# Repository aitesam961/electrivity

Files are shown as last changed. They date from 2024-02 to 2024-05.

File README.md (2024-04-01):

# ELECTRIVITY: An EDGE IOT SYSTEM
A wireless IoT system with AI enhanced processing and automation.

### List of Hardware Components
- Check [HARDWARE](hardware/readme.md)
- Check [MQTT Topics](application/topics_mqtt.md)

## STATUS
In Progress.

- Hardware and Firmware : @aitesam961
- Mobile application and Linux Program: @Hassan & @Fawad

## File Naming Conventions

The project files follows a uniform file naming convention across the repository.

### Design Files: 
Design files should be placed under respective folders and DE project sources should be named as:
```
EVTY_FW_PIO_V1
EVTY: Electrivity
FW: Firmware 
PIO: Development Environment
V1: Version
```

The provided FNC follows guidelines provided by [MIT Data Management:
File Organization documents](https://ocw.mit.edu/courses/res-str-002-data-management-spring-2016/497580bd31c004cc758a2afb0a115aa4_MITRES_STR_002S16_File.pdf)
### Documents:
Documents must follow the naming order as the example below

```
EVTY_pres_sysd_v1.xls
EVTY: Electrivity
pres: presentation
sysd: Descriptor
v1: version
.xls: extension
```

### Directory Tree

```
.
├── archive
│   ├── _apppy
│   │   ├── blecclient.py
│   │   ├── blehandshake.py
│   │   └── bleserial.py
│   ├── BT_MAC_scan
│   │   └── BT_MAC_scan.ino
│   ├── _EIS_fw
│   │   ├── ESP_Control.cpp
│   │   ├── ESP_SENSOR.cpp
│   │   ├── firmware.code-workspace
│   │   ├── include
│   │   │   └── README
│   │   ├── lib
│   │   │   └── README
│   │   ├── platformio.ini
│   │   ├── src
│   │   │   └── main.cpp
│   │   └── test
│   │       └── README
│   └── ESP32_BTSerial
│       └── ESP32_BTSerial.ino
├── docs
│   ├── EVTY_arch_blueprint_v1.pdf
│   ├── EVTY_part_list_phase1_v1.pdf
│   ├── EVTY_part_list_prelim_v1.pdf
│   ├── EVTY_poc_demo_doc_v1.pdf
│   ├── EVTY_poc_demo_v1.drawio
│   ├── EVTY_poc_demo_v1.png
│   ├── EVTY_pres_phase1_v1.pdf
│   ├── im1.jpeg
│   ├── im2.jpeg
│   ├── im3.jpeg
│   ├── image_2024-02-22_001135263.png
│   ├── images
│   │   ├── image1.jpeg
│   │   ├── image2.jpeg
│   │   ├── image3.jpeg
│   │   ├── image4.jpeg
│   │   ├── image5.jpeg
│   │   └── image6.jpeg
│   ├── poc_demo.md
│   ├── prism-xp1_swd.drawio
│   ├── prism-xp1_swd.png
│   ├── prism-xp1_sysd.drawio
│   ├── prism-xp1_sysd.jpg
│   ├── readme.md
│   └── Report.pdf
├── firmware
│   ├── EVTY_FW_ARDPIO_v1
│   │   ├── debugger_esp.cpp
│   │   ├── esp32_r2.cpp
│   │   ├── esp32_r3.cpp
│   │   ├── esp32_r4.cpp
│   │   ├── esp32_s1.cpp
│   │   ├── esp_r1.cpp
│   │   ├── include
│   │   │   └── README
│   │   ├── lib
│   │   │   └── README
│   │   ├── platformio.ini
│   │   ├── src
│   │   │   └── main.cpp
│   │   └── test
│   │       └── README
│   ├── readme.md
│   └── test_builds
│       ├── r1_cRtos.c
│       └── s1_cRtos.c
├── hardware
│   ├── 3dmodel
│   │   ├── EVTY_stackupmodel_v1.blend
│   │   ├── EVTY_stackupmodel_v1.blend1
│   │   └── lib
│   │       ├── 4 Channel Relay Board.stl
│   │       ├── 4 Channel Relay Board.stp
│   │       ├── ESP32-DEVKITC-32D--3DModel-STEP-269445.STEP
│   │       ├── ESP32-DEVKITC-32D--3DModel-STEP-269445.stl
│   │       ├── m3-16mm.STEP
│   │       ├── m3-16mm.stl
│   │       ├── nut.STEP
│   │       ├── nut.stl
│   │       ├── Power_Board_asm.STEP
│   │       ├── Power_Board_asm.stl
│   │       ├── proto_7x5.stl
│   │       └── proto_7x5.stp
│   ├── EVTY_XP1_SBcase_v1p0
│   │   ├── CAM_Data
│   │   │   ├── EVTY_bracket_custom_v1p0-Prim Shell.step
│   │   │   ├── EVTY_bracket_custom_v1p0-Prim Shell.stl
│   │   │   ├── EVTY_bracket_custom_v1p0-Side Face.step
│   │   │   └── EVTY_bracket_custom_v1p0-Side Face.stl
│   │   └── src_freecad
│   │       ├── EVTY_bracket_custom_v1p0.FCStd
│   │       └── EVTY_bracket_custom_v1p0.FCStd1
│   ├── physical_addresses.md
│   ├── readme.md
│   └── schem
│       └── EVTY_Schematics_brd_v1.0.pdf
├── linux_app
│   ├── mqttapp.py
│   ├── mqtt_switch_control.sh
│   └── topics_mqtt.md
├── mobile_app
│   └── EVTY_distribution_plan_v1.md
├── osimage
│   └── readme.md
├── README.md
└── reference
    ├── mqtt-v5.0-os.pdf
    └── TTP223.pdf

30 directories, 82 files

```

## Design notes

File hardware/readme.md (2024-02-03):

## List of Components

| Component | Status  | Qty | Description |
|---|---|-----|---|
| -- Edge Device | | | |
| Raspberry Pi 5 | Acquired| 1 | 8GB |
| Pi5 Power Adapter (5V 5A) | YTA | 1 | |
| micro SD Card | Acquired| 1 | |
| Pi5 Active Cooler  | YTA | 1 | |
| micro HDMI adapter | YTA | 1 | |
| Coral TPU | YTA | 1 | USB-stick |
| | | | |
| -- Client Devices | | | |
| ESP32-Devkits | Acquired| 4 | wroom-32 (CP2102) |
| Relay module | Acquired| 1 | 4-channel |
| Current Sensor | YTA | 3 | zmct103-5a |
| Light sensor | Acquired| 3 | LDR with amplifier |
| Environment Sensor | Acquired| 2 | DHT-11 |
| Switch Board | Acquired| 1 | 4-Switch, 4-Sockets |
| Socket bulbs | Acquired| 2 | 220VAC |
| Power Adapter | Acquired| 3 | 5V-1A (micro-USB Cables)  |
| | | | 
| Misc. suppliers | | | |
| Perf-boards | Acquired| 2 | Dotted |
| Breadboard | Acquired| 2 | single-size |
| Wire 24AWG | Acquired| 1 | solid core pair (3m) |
| Wire 16AWG | Acquired| 1 | multi-stranded(2m) |
| Resistors | Acquired| 20  | 1k, 10k, 100k |
| Capacitors | Acquired| 10  | 1uF, 10uF |
| Terminal blocks | Acquired| 10  | 2p-3A |
| Thermal sleeve | Acquired| 2 | (20mm, 4mm) |

  ### Off-the-shelf Clients

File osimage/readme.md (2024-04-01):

### Raspberry Pi OS
- 64-bRaspberry Pi OS with desktop
- Release date: December 5th 2023
- System: 64-bit
- Kernel version: 6.1
- Debian version: 12 (bookworm)
- Size: 1,108MB
- [Release notes](https://downloads.raspberrypi.com/raspios_arm64/release_notes.txt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..)

$ sudo raspi-config params

- SSH Enabled
- Default boot to CLI (performance constraints)
- username: rpi
- password: rpirpi
- Wireless Interface
 (aitesam's home network) or can be configured

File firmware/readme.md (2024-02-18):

- ESP32-Devkit-A1 MAC_ADDR  [08:D1:F9:E7:DE:12]

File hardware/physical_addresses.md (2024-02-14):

## Physcial Addresses of ESP32 Servers

### E1
ESP32 MAC Address: 08:D1:F9:E7:DE:12

### E2 
ESP32 MAC Address: 08:D1:F9:E8:7E:7C

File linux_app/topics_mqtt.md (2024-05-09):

### List of MQTT topics
```
prism/board1/switch1
prism/board1/switch2
prism/board1/switch3
prism/board1/switch4

prism/board2/switch1
prism/board2/switch2
prism/board2/switch3
prism/board2/switch4

prism/board3/switch1
prism/board3/switch2
prism/board3/switch3
prism/board3/switch4

prism/board4/switch1
prism/board4/switch2
prism/board4/switch3
prism/board4/switch4

prism/board1/touch1
prism/board1/touch2
prism/board1/touch3
prism/board1/touch4

prism/board2/touch1
prism/board2/touch2
prism/board2/touch3
prism/board2/touch4

prism/board3/touch1
prism/board3/touch2
prism/board3/touch3
prism/board3/touch4

prism/board4/touch1
prism/board4/touch2
prism/board4/touch3
prism/board4/touch4

prism/sboard1/sensor1
prism/sboard1/sensor2
prism/sboard1/sensor3

prism/board1/pwrch1
prism/board1/pwrch2
prism/board1/pwrch3
prism/board1/pwrch4

prism/board2/pwrch1
prism/board2/pwrch2
prism/board2/pwrch3
prism/board2/pwrch4

prism/board3/pwrch1
prism/board3/pwrch2
prism/board3/pwrch3
prism/board3/pwrch4

prism/board4/pwrch1
prism/board4/pwrch2
prism/board4/pwrch3
prism/board4/pwrch4

```

**There are 4x switches/touches per board. As the first step, implement support for at least 4 boards.**

### Standard Message strings

#### From Client to RPi

- a = `high`

- a = `low`

#### From RPi to Clients

- publish(`on`)

- publish(`off`)

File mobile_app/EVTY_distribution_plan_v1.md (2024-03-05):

# XP-1: Client Distribution

Each room gets allocated a single board ID (i.e board1, board2 ...). This scheme will slightly differ for the production model.

### Bed Room:
```
prism/board1/switch1	
prism/board1/switch2
prism/board1/switch3
prism/board1/switch4
```
```
prism/board1/touch1
prism/board1/touch2
prism/board1/touch3
prism/board1/touch4
```
### Living Room:
```
prism/board2/switch1
prism/board2/switch2
prism/board2/switch3
prism/board2/switch4
```
```
prism/board2/touch1
prism/board2/touch2
prism/board2/touch3
prism/board2/touch4
```
### Kitchen:
```
prism/board3/switch1
prism/board3/switch2
prism/board3/switch3
prism/board3/switch4
```
```
prism/board3/touch1
prism/board3/touch2
prism/board3/touch3
prism/board3/touch4
```
### Lawn:
```
prism/board4/switch1
prism/board4/switch2
prism/board4/switch3
prism/board4/switch4
```
```
prism/board4/touch1
prism/board4/touch2
prism/board4/touch3
prism/board4/touch4
```

## Valid Strings

#### Switches

Hardware clients subscribe to `switch` topics across the network and read values. The valid string values are `on` and `off`. All other values execute exception case.

#### Touch

Hardware publishes the `touch` topics ON CHANGE ONLY. Whenever a user touches the sensor, a `high` signal is published and the publisher goes silent. The raspberry pi stores this `on` state until user touches the same sensor again OR mobile app changes the state. 
The valis strings for touch published by the user are `high` and `low`. The raspberry pi is responsible for exception handling in this regard.

### Add or Remove Devices

User can add or remove available devices through mobile app. RPi uses client.subscribe(x,x) or client.unsubscribe(x,x) functions of MQTT to add or remove devices. Mobile app uses its own set of signals to send or receive data from RPi that eventually execute addition or removal of devices.

**NOTE: No Sensors are active for this prototype. If mobile app may or may not include interface for sensors for XP-1 but production version will certainly use sensor inputs.**

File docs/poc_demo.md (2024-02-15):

# Proof-of-Concept Demonstration

## Setup
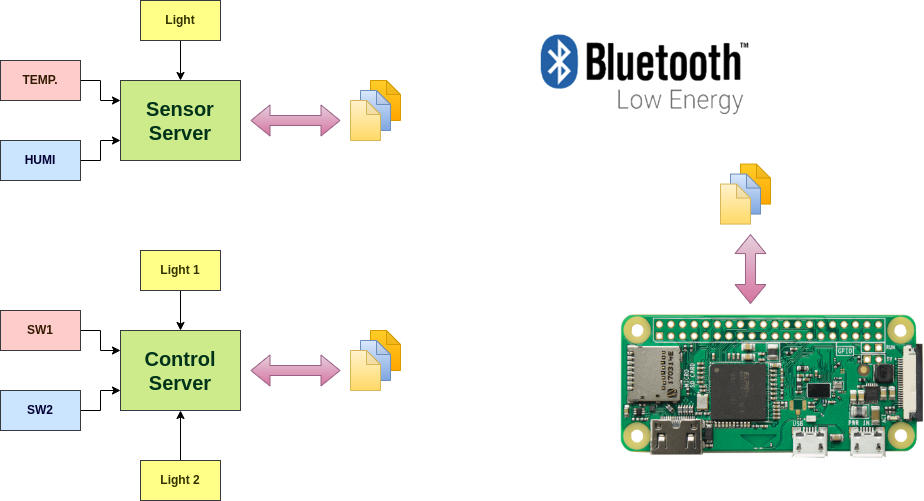
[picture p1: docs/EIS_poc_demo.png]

###  ESP32-S1  (Server 1)

Basically a sensor device. Integrates a DHT-11 temperature, humidity sensor and an analog light sensor. The ESP32 advertises a BLE GATT server profile and allows connection with Raspberry pi Client against known UUIDs.

Temp, Humi and Light intensity, each has a unique GATT chracteristic.The system is powered by a micro-USB power adapter.

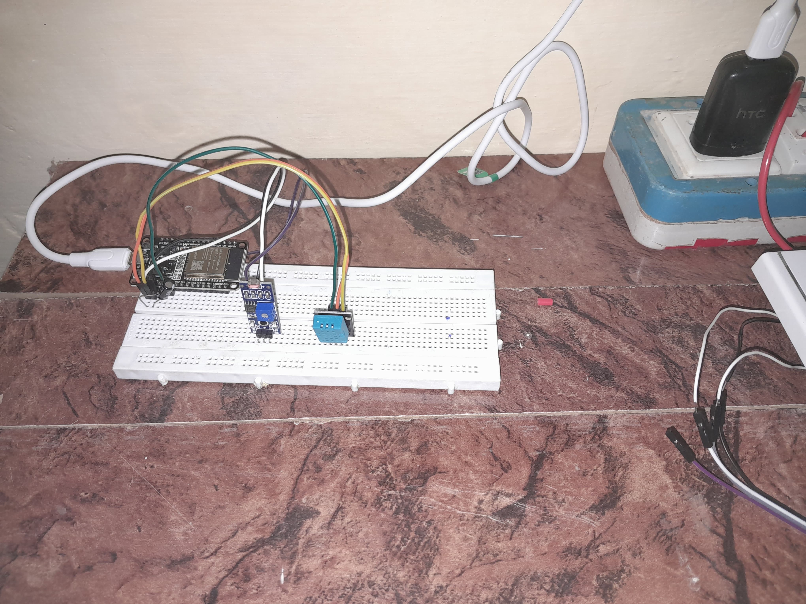
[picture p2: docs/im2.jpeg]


###  ESP32-S2  (Server 2)

Primarily acts as a relay controlling device. The GPIOs connect to a relay board. The resistors are for current limiting to keep ESP32 in safe operational range.The Relay board connects to a household Wall Switch board that has AC Bulbs for indication.

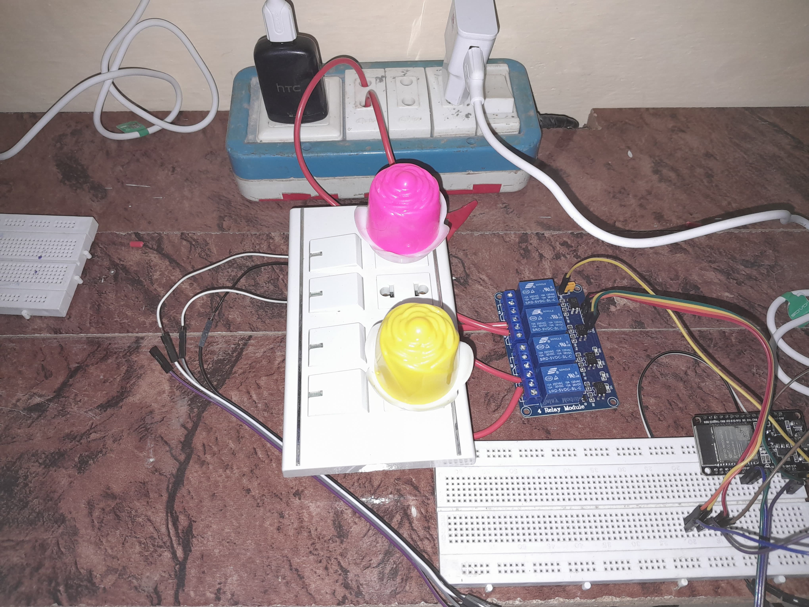
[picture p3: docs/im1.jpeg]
Im2


Moreover, the pushbuttons emulate user actions against switches. (Demo Alternative until current sensors arrive).

The system is powered by power adapter directly from the socket.

### Raspberry pi Zero W Central Client

Pi Zero W acts as a central client. (Pi-5 is not in use because of missing accessories.)

It runs a python program with root permissions. Makes use of bluepy library for bluetooth Communication profiles.
The UUIDs and MAC addresses of server devices are already stored in the program.

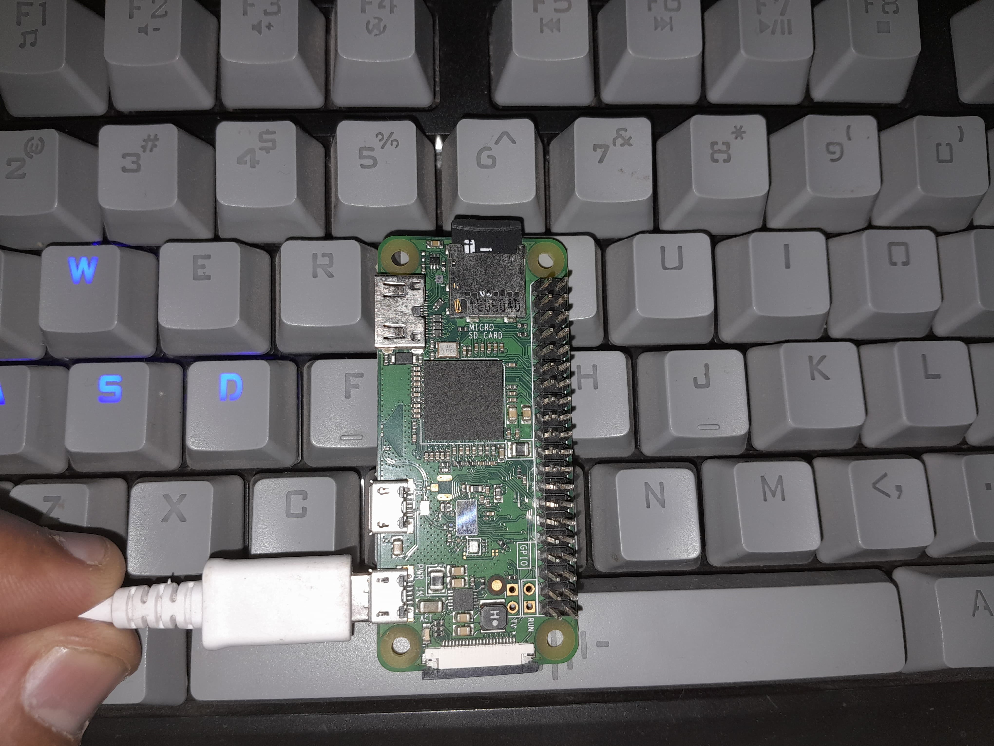
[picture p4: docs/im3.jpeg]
Im3


### Wireless Access Point

Not neccessary but helps access the pi thorugh SSH for convenient configuration. Eventually, would allow for WAN connection to mobile app.

## Operation
This demonstration includes a sensor server and a control server. The wireless communication is implemented using BLE GATT standard communication protocol.

At the boot-up, the servers wait for the central client to connect. At this time, a blue LED on ESP32 is turned ON. The Raspberry pi client connects to servers using their MAC addresses that are pre-defined in the client application.

After successful pairing, Sensor Service reads the sensor data and transmits a GATT Chracterisitic for each field. Raspberry Pi reads the chracteristics and asserts the control signals accordingly.

In this demo, one of the switch is dedicated to controlling yellow light. This presents the complete process of rpi client reading the switch through ESP32 and triggering the relay to turn ON. The Pink Light is triggered by an LDR. Whenever it finds the light is indufficient, it turns on the light. This demonstrated a sensor based decision.

### Operational Range

Using the BLE GATT channel with ESP32 connected to my Phone, I experienced a very good range of ~11 meters (apologies: 15 in the video was an approximate measurement). In case of ESP32 connected to raspberry pi zero w over BLE 4.2 GATT, I experienced the range dropping at ~4-5 meters.(BLE + WiFi active). So clearly, RPi is the bottleneck.

### Log (rpi console)

```
aitesam961@latitude:~$ ssh pi0wh@192.168.8.102
pi0wh@192.168.8.102's password: 
Linux raspberrypizero 6.1.0-rpi8-rpi-v6 #1 Raspbian 1:6.1.73-1+rpt1 (2024-01-25) armv6l

The programs included with the Debian GNU/Linux system are free software;
the exact distribution terms for each program are described in the
individual files in /usr/share/doc/*/copyright.

Debian GNU/Linux comes with ABSOLUTELY NO WARRANTY, to the extent
permitted by applicable law.
Last login: Thu Feb 15 13:28:32 2024 from 192.168.8.107
pi0wh@raspberrypizero:~ $ cd bleapp
pi0wh@raspberrypizero:~/bleapp $ ls
blecclient.py  blehandshake.py  bleserial.cpp  bleserial.py  readme.md
pi0wh@raspberrypizero:~/bleapp $ sudo python3 blecclient.py
Waiting for sensor notifications...
Temperature: 18 °C
Humidity: 43 %
Light Status: 0
Switch 1: 0
Switch 2: 1
Light 1 turned: ON
Light 2 turned: ON
Waiting for sensor notifications...
Temperature: 18 °C
Humidity: 43 %
Light Status: 1
Switch 1: 0
Switch 2: 1
Light 1 turned: OFF
Light 2 turned: ON
Waiting for sensor notifications...
Temperature: 18 °C
Humidity: 43 %
Light Status: 1
Switch 1: 0
Switch 2: 1
Light 1 turned: OFF
Light 2 turned: ON
Waiting for sensor notifications...
Temperature: 18 °C
Humidity: 43 %
Light Status: 1
Switch 1: 0
Switch 2: 1
Light 1 turned: OFF
Light 2 turned: ON
Waiting for sensor notifications...
Temperature: 19 °C
Humidity: 44 %
Light Status: 1
Switch 1: 0
Switch 2: 1
Light 1 turned: OFF
Light 2 turned: ON
Waiting for sensor notifications...
Temperature: 19 °C
Humidity: 44 %
Light Status: 0
Switch 1: 0
Switch 2: 1
Light 1 turned: ON
Light 2 turned: ON
Waiting for sensor notifications...
Temperature: 19 °C
Humidity: 44 %
Light Status: 1
Switch 1: 0
Switch 2: 1
Light 1 turned: OFF
Light 2 turned: ON
Waiting for sensor notifications...
Temperature: 19 °C
Humidity: 44 %
Light Status: 0
Switch 1: 0
Switch 2: 1
Light 1 turned: ON
Light 2 turned: ON
Waiting for sensor notifications...
Temperature: 19 °C
Humidity: 44 %
Light Status: 1
Switch 1: 0
Switch 2: 1
Light 1 turned: OFF
Light 2 turned: ON

```
### Summary

This is the proof-of-concept demonstration of the system working with basic features as reading from sensors and toggling light switches.
Several improvements and additions have yet to be made. However, this demonstration presents an end-to-end system operation with complete software stack implementation following the hard standards and best design practices.
More functionalities have yet to come.

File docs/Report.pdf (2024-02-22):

# Home Automation

Prepared by Hassan Malik
on Feb 21, 2024

Establish an MQTT broker on a Raspberry Pi for efficient device communication. Develop hardware devices (sensors, actuators) as MQTT clients.
Create a mobile app that connects to the MQTT broker, allowing users to monitor and control devices.
Implement real-time updates on the mobile app based on MQTT messages.

### PROJECT DESCRIPTION

### TOOLS

MQTT Broker: Mosquitto on Raspberry Pi.
Hardware: Custom devices acting as MQTT clients.
Mobile App: Developed using Flutter/React for cross-platform compatibility.

### FEATURES

Implemented MQTT connection logic in the Flutter/React Native app. Configured connection settings with the Raspberry Pi MQTT broker.
Developed an intuitive user interface for real-time monitoring and control using Flutter/React Native.
Enabled the app to subscribe to relevant MQTT topics for sensor data and control commands. Allowed users to control devices through the app, sending commands via MQTT.
Provided a consistent and user-friendly experience

### SECURITY MEASURES

Implemented username/password authentication for MQTT broker.
Ensured secure MQTT connections between the Flutter/React Native app and the broker. Encrypted sensitive data exchanged between devices and the app.

### FUTURE ENHANSMENT

Implementation of machine learning algorithms for predictive automation.
Expansion of device compatibility and support.

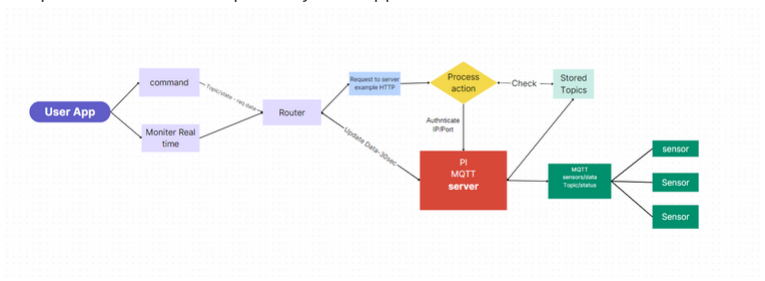
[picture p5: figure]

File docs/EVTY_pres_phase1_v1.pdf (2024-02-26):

# PRISM: An Edge IoT System for Home Automation

# Presentation: XP0.1

# Introduction

## A smart home automation and monitoring solution with focus on

security and privacy.

## This project makes use of Internet of Things to streamline the monitoring and control of household applications with special care to the user’s privacy and

security concerns.

# Quick Overview -I

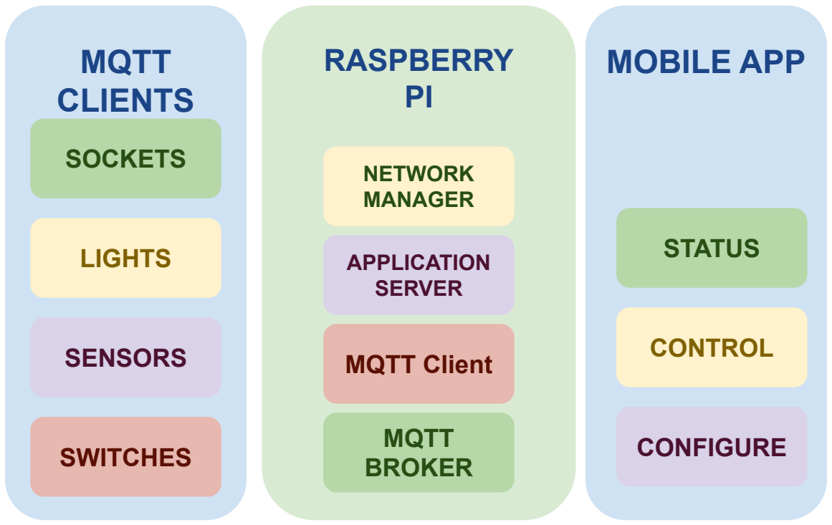
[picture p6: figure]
SOCKETS; LIGHTS; SENSORS; SWITCHES; MQTT CLIENTS; MQTT BROKER; APPLICATION SERVER; MQTT Client; NETWORK MANAGER; RASPBERRY PI; STATUS; CONTROL; CONFIGURE; MOBILE APP

# Network Architecture

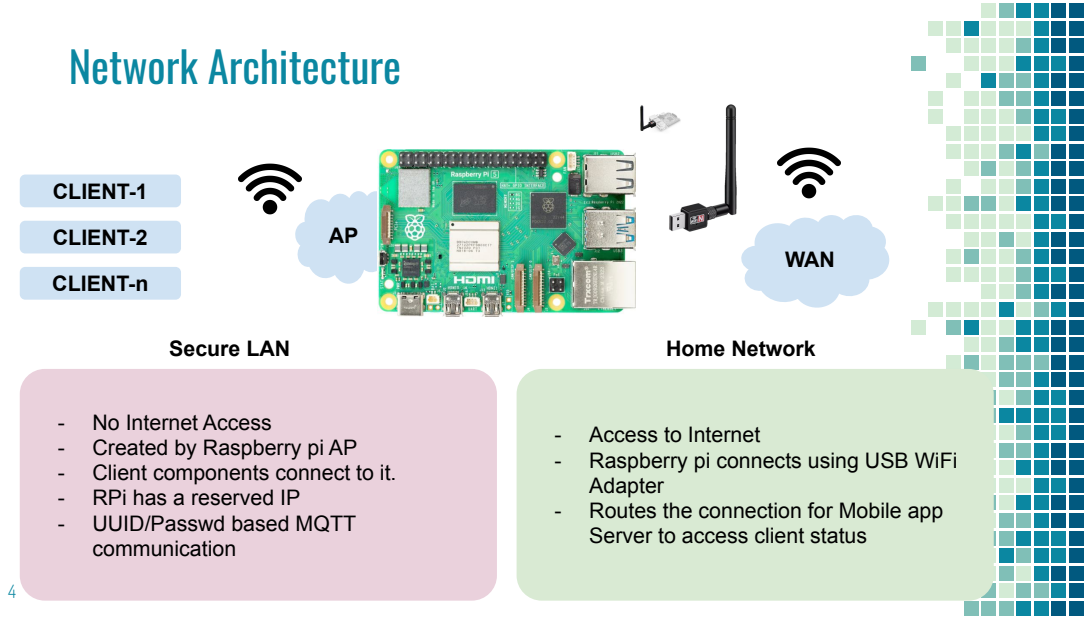
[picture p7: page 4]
Secure LAN; Home Network; CLIENT-1; CLIENT-2; CLIENT-n; WAN

- No Internet Access
- Created by Raspberry pi AP
- Client components connect to it.
- RPi has a reserved IP
- UUID/Passwd based MQTT
communication

- Access to Internet
- Raspberry pi connects using USB WiFi
Adapter
- Routes the connection for Mobile app
Server to access client status

# TYPICAL APPLICATION

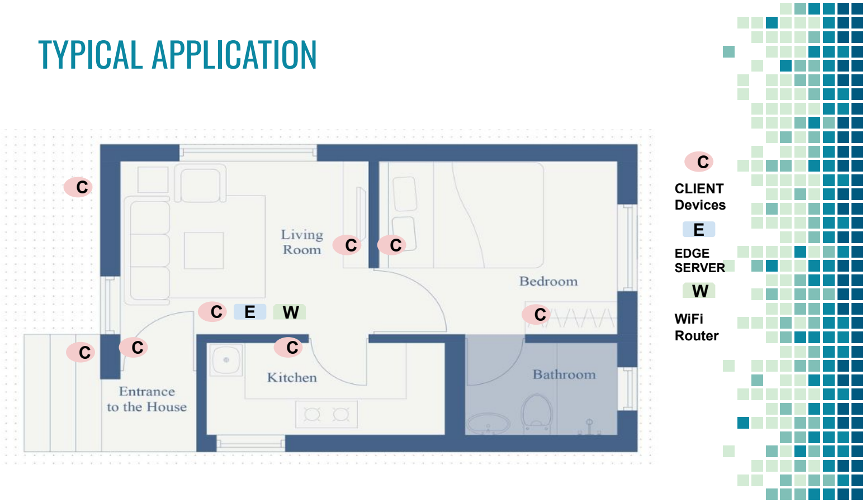
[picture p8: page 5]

C

C

C | C | C

C

C

C

E W

C

CLIENT
Devices

EDGE
SERVER

WiFi
Router

E

W

# XP0.1 Hardware Setup

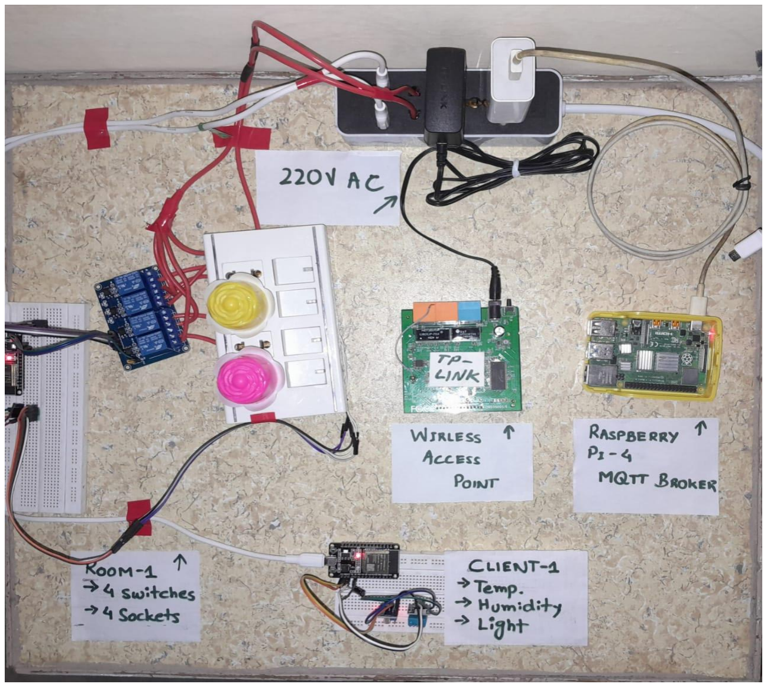
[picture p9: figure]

## - Raspberry pi Central Server - WiFi Access Point - Client-1: Sensors - Client-2: Household

switchboard (4-switch,

## 4-sockets) - Power Source (220VAC)

# Future Plans (XP1.0 and beyond)

XP1.0

# - A complete solution for monitoring and

controlling switchboards.
- End-to-end network and software stack.

# - Approach to a User Configurable, flexible

design.

# - Off-the-shelf Hardware components

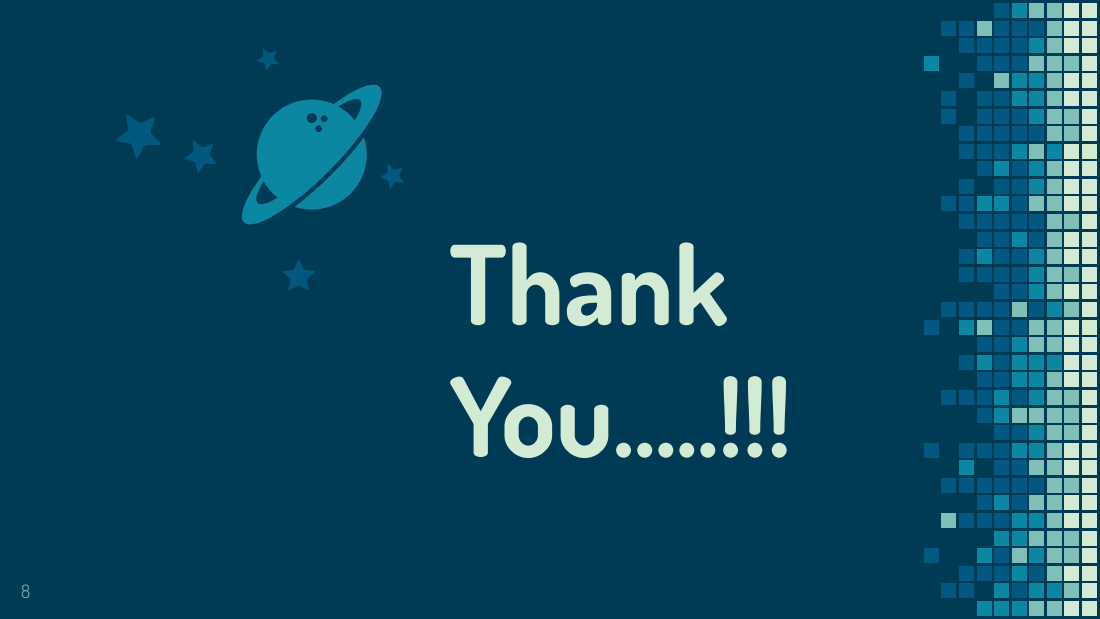
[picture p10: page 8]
Thank You…..!!!

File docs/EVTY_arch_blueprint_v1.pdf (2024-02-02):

# Edge IoT System

## ARCHITECTURAL BLUEPRINT

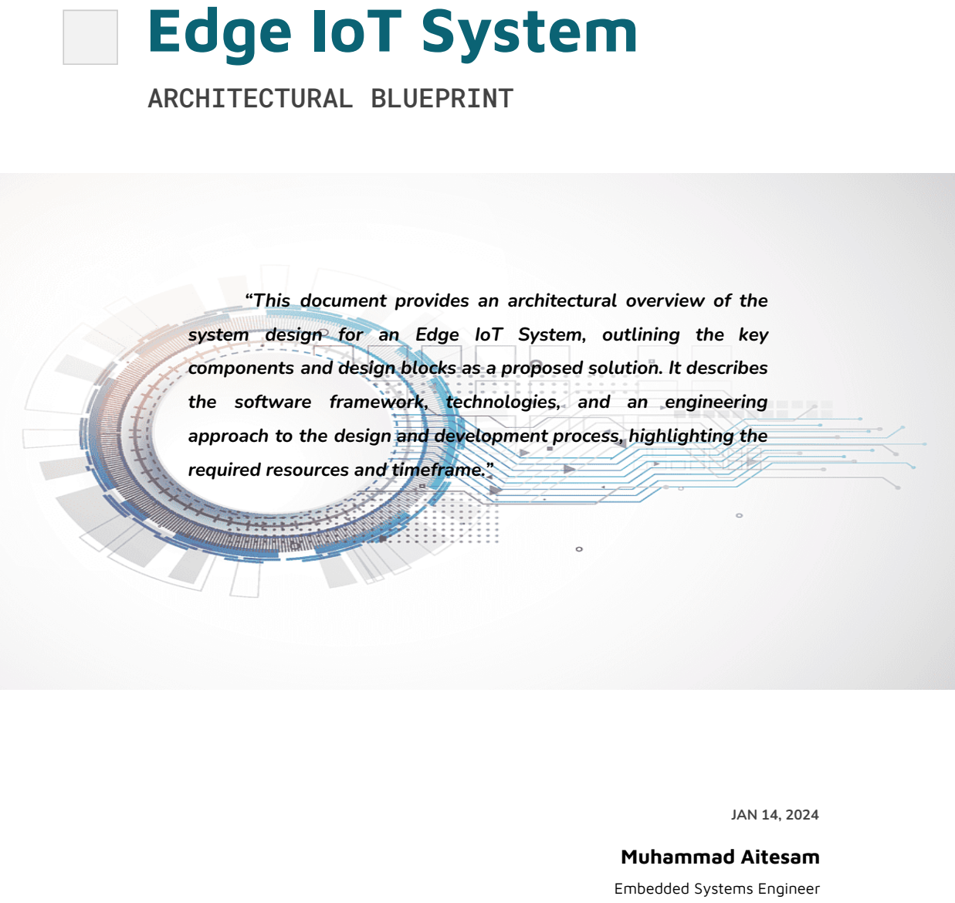
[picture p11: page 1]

“This document provides an architectural overview of the system design for an Edge IoT System, outlining the key components and design blocks as a proposed solution. It describes the software framework, technologies, and an engineering approach to the design and development process, highlighting the required resources and timeframe.”

JAN 14, 2024
Muhammad Aitesam

Embedded Systems Engineer

## 1. Project Overview

This document outlines development of an Edge IoT system focused on monitoring activities using a suite of sensors installed at the facility. Aimed at monitoring the activities of old age people, this system allows controlling household appliances remotely and monitoring status of multiple variables in real-time. Allowing users to access this data through mobile devices adds convenience to the monitoring and controlling practices. Artificial Intelligence aided processing further ensures the monitoring of usage patterns and allows an optimised control over the devices. Scalability and configurability are the key objectives that ensure a bespoke solution. To ensure user’s privacy, the system aims to store and process data within a local host without transmission to any remote database or client with the exception of a secure link to mobile application.
The system aims to support various types of input patterns including monitoring of appliances, doors and to keep track of medicine schedules for elderly.

## 2. Challenges

The scalable nature of this project poses a significant challenge to the design. It’s not only about adding new devices to the network. It includes modification at several layers in the design to accommodate those additions and changes. It covers the addition of software support for that device, adding its inputs to the compute layer to weigh in the data. Moreover, it requires adding blocks to the application layer in order to present that data to the user. Not all the sensors and control devices are the same as each may have data of a different category. The solution requires development of a generic software IO port that could offer compatibility with all types of supported input and output devices. The processing system needs to be able to recognize each device and weigh its data as per the demands.

## 3. Hardware

The initial prototype comprises off the shelf (COTS) hardware and modules for quicker PoC turnaround (C1 Hardware). After successful PoC, more improvements could be made to design customised hardware for sensor nodes and edge devices to ensure a more bespoke solution(C2 Hardware).

C1 Hardware

- Raspberry Pi 4, Raspberry Pi 5 is preferred
- Google Coral TPU (USB Accelerator for RPI4, M.2 PCIe Accelerator for RPI5)
- ESP32 Dev Kits / nRF52 Dev kits
- Sensor modules
- Controller modules (relays, FET switches etc)
- RPI GSM/ISM Cellular HATs
C2 Hardware
- RPI CM4 or RPI 5 SBC
- Custom designed carrier board
- USB Accelerator slot or M.2 Slot PCIe accelerator slot
- On Board Power Supply
- Custom Designed sensor nodes with integrated sensor + MCU
- Enclosure + Thermal relief system.

## 4. Software

- MQTT broker running on raspberry pi would allow integration of various modules and sensors with the core framework.
- MQTT Client running on MCU with RTOS enabled control.
- A configurator application (Flutter/React based) to allow taking commands from mobile app to add or remove devices and their respective data processing streams inside the main compute block.
- AI specific frameworks (Tensor/PyTorch etc)
- python3 based PyCoral compute offload to accelerator
- Zephyr RTOS for MCU

## 5. Systematic Block Design

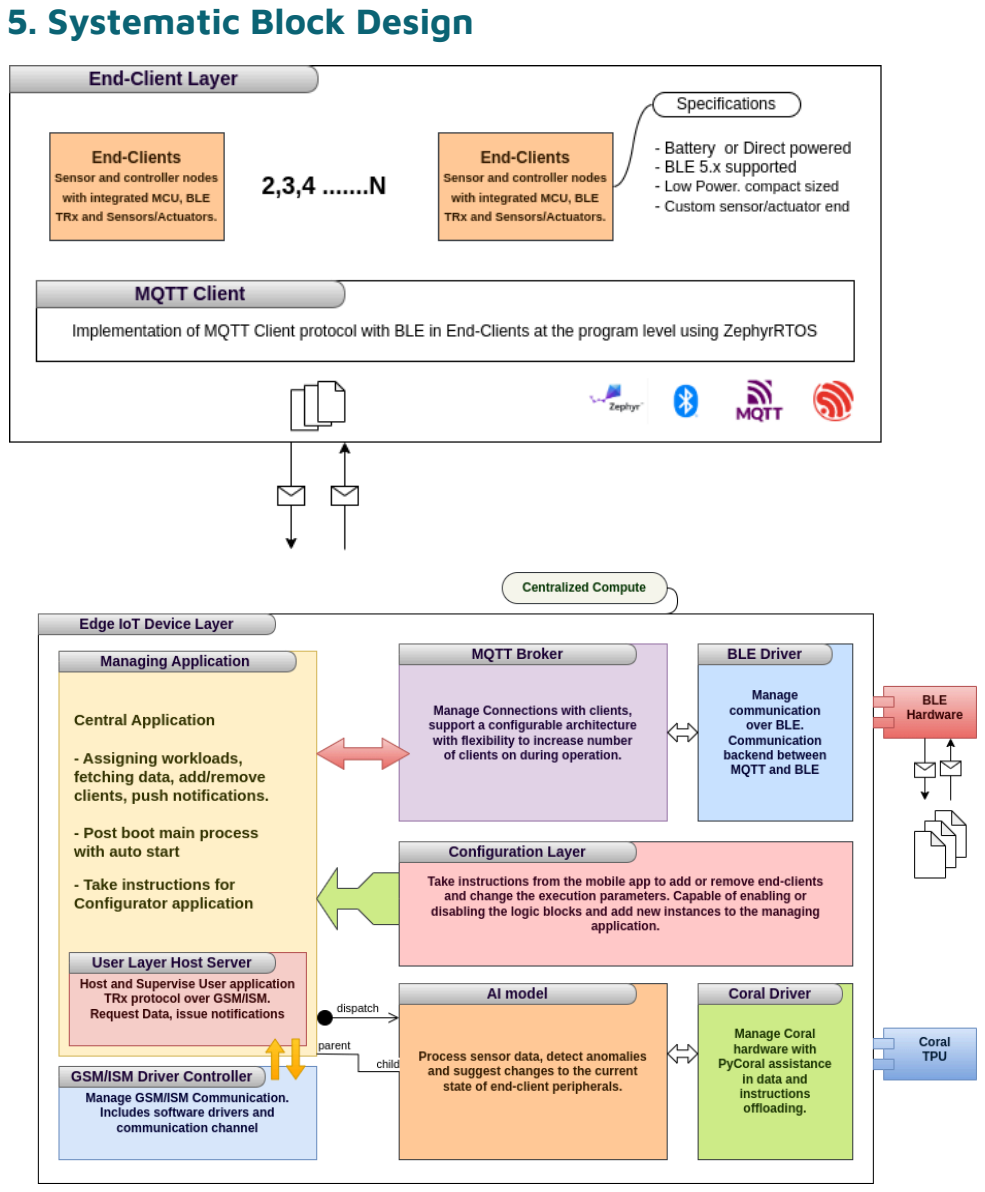
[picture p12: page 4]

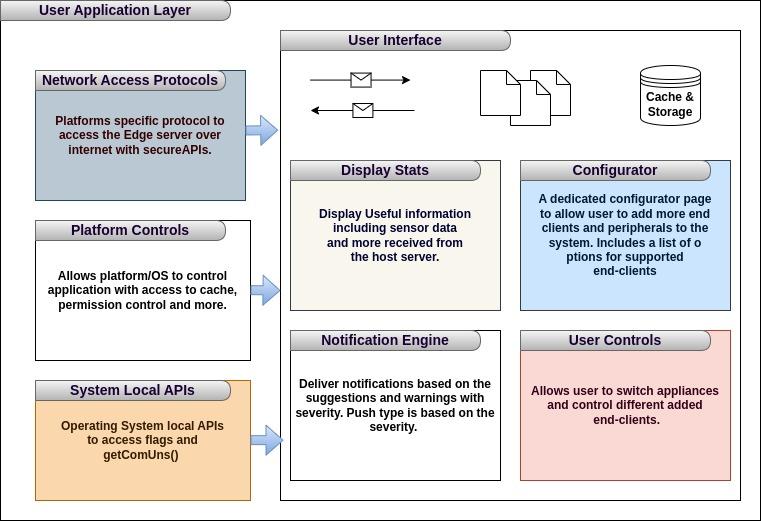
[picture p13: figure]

## 6. Resources

## Engineers and Developers:

1- AI Specialist

Requires experience with design and implementation of AI model to detect anomalies and provide suggestions based on the received sensor data. Understanding of optimization techniques for low power hardware are desired and experience with software integration is a plus.
2- Embedded Hardware Engineer

Requires experience with design of custom hardware with microcontrollers, wireless transceivers (BLE) and various types of sensors and actuators. Experience with manufacturing, board bring-up and troubleshooting is desired and understanding of firmware development is a plus.

Works closely with Embedded Software Engineer.
3- Embedded Software Engineer

Requires experience with creating custom applications in the linux environment. Experience with creating firmware for custom devices is desired and understanding of HAL (hardware abstraction layer) is a plus.

Works closely with Embedded Hardware Engineer and AI Specialist.

Note: May need more than x1 person for this role given the amount and scope of workload.
4- Mobile Application Developer

Requires experience with Android/IOS mobile apps including frontend and backend. Experience in creating a secure link with a custom host is required and understanding of secure communications is a plus.

Works closely with Embedded Software Engineer.

## Equipment and Workspace:

- Access to C1 Hardware
- Workspace and workstations for team

## 7. Expected Timeframe

With the availability of engineers and developers, a C1 Hardware based solution could be prepared for demonstration in ~3 months. For added compatibility and support for a wider range of devices, the customised hardware solution and with maximum capabilities and complete testing could be completed in expected 7-8 months. These estimates are based on my past experience. It may vary depending on expertise of the team and working conditions.

## About me

I am Aitesam, an engineering graduate with passion to work on embedded solutions.

I develop hardware and software solutions for commercial and industrial applications. Over the past 4 years, I undertaken several endeavours including my role as a freelance embedded solutions provider working with clients globally to develop electronics systems tailored to their requirements.

I also worked as a consultant helping my clients with expert review for their hardware designs before manufacturing, helping with troubleshooting and EMC compliance issues.

Over the last year, I have worked on development of FPGA based solutions including the development of RISC-V Vector extension for RV64 systems. It included design of architecture in compliance with RV-V Spec and the RTL implementation targeted for Xilinx Zynq-US+ FPGAs.

In regards to the IoT category, I have developed several systems for my clients. To name a few, I have developed multiple types of home automation equipment including DIN Rail mounted WiFi based controllers. To be more specific, I have developed a monitoring solution targeted for elderly care space. It included design of customised hardware to monitor the kitchen stoves to avoid the possibility of fire in case it is left open by mistake. Moreover, it involved monitoring the doors at home. The sensors were wirelessly connected to a raspberry pi powered hub running the MQTT broker. The hardware design featured highly efficient components enabling battery run-time of approx. 1.5 years.

I enjoy working on open source projects as a way to return back to the community. Which can be found on GitHub. For more information, check my LinkedIn profile.

Linkedin/MAitesam (http://www.linkedin.com/in/muhammad-aitesam) | Github/aitesam961 (https://github.com/aitesam961) | aitesam961@gmail.com

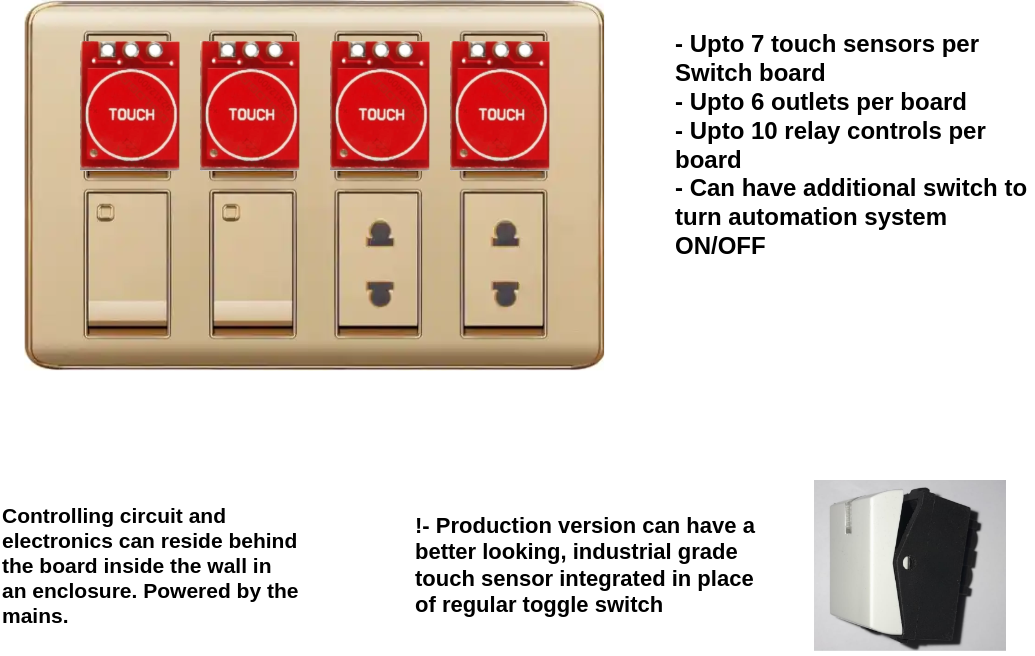
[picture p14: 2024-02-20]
docs/prism-xp1_swd.png

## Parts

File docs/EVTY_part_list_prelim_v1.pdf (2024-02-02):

# Edge IoT System

## N1: Hardware Components: Edge Device

Components | Qty | Ref URL | Comments
Raspberry Pi 5 | 1 | URL (https://www.raspberrypi.com/products/raspberry-pi-5/) | Already Acquired
RPI power Adapter | 1 | URL (https://www.raspberrypi.com/products/27w-power-supply/) | To be purchased
RPI Active cooler | 1 | URL (https://www.raspberrypi.com/products/active-cooler/) | To be purchased
micro SD Card | 1 | URL (https://www.daraz.pk/phone-micro-sd-cards/) | Already Acquired
Google Coral TPU | 1 | URL (https://coral.ai/products/accelerator) | To be purchased

## N2: Hardware Components: COTS integrated controllers

There are integrated sensor and wall socket solutions available in the market but for the vast majority of them, the key challenge is their proprietary wireless interface discouraging integration with custom devices. The very common example is Phillips Hue Bulbs. Many of such devices use WiFi and allow a very limited control in reprogrammability. We can never be sure about what communications these devices might want to establish over the internet.
However, some devices in this domain that feature a programmable microcontroller and BLE connectivity are hack-able which means with some tweaks, they can be re-programmed for a customized job as needed but there is no certainty of success with these devices. An example is Xiaomi MIjia Temperature sensor. (https://cloudfree.shop/product/xiaomi-mijia-bluetooth-temperature-and-humidity-sensor/) The same example applies to some switching and monitoring applications.
I have shortlisted a few of such devices in the table below. However, there is no guarantee of success with re-programmability and customizability for our needs. Please see comments for each option.

Device | Description | URL | Comments
Cloudfree Smart Plugs | Extension adapter for wall sockets. (SonOff S31) | URL (https://cloudfree.shop/product-category/smart-plugs/) | Integrated Controller. Runs Tasmota/ESPhome and is programmable with specialized builder and binaries.
Cloudfree Light Switch | Light Switch (1x SPDT) with ESP32 integrated controller | URL (https://cloudfree.shop/product/cloudfree-light-switch/) | Built around ESP32-C3 so very much configurable and controllable.
Athom Smart Plug | ESP32-C3 AU Plug V3 | URL (https://www.athom.tech/blank-1/tasmota-esp32-c3-au-plug-v3) | Built around ESP32-C3 so very much configurable and controllable.
Sonoff MINI R4 | An All purpose switch featuring ESP32 | URL (https://sonoff.tech/product/diy-smart-switches/minir4/) | Basically a multi-purpose controller for seamless integration inside wall sockets and switches
Shelly Plugs | A wide range of EU, US, AU, UK plugs with integrated ESP32 based controllers. | URL (https://www.shelly.com/en/products/shop/shelly-qubino-wave-i4-dc) | Basically a multi-purpose controller for seamless integration inside wall sockets and switches

The ESP32 is a very common chipset in the commercial home automations sector especially because of its high performance, low cost and easy availability. Moreover, it’s wireless frontend is FCC approved which makes it a suitable option in small batch commercial segment.
What’s important for us is that the ESP32 chipset has integrated WiFi/BLE and it is easily programmable over the standard UART interface which is easy to identify in custom boards. If we use an off-the-shelf integrated solution, we can likely access it’s programming interface with little effort. However it is not a guaranteed solution but has a good probability of success.

## N3: Hardware Components: Pre-assembled basic solutions

Device | Description | Comments
KiCony ESP32 Automation Controller (https://www.kincony.com/arduino-esp32-4-channel-relay-module.html) | Can be used without any Devkit. A pre assembled solution with 8-Channel Inputs and outputs | The main controller board integrat-able with different IO devices. Features integrated BLE/WiFi

## N4: Hardware Components: Self assembly solutions

Device | URL | Comments
ESP32-Dev Kits | URL (https://www.amazon.com/ESP32-WROOM-32-Development-ESP-32S-Bluetooth-Arduino/dp/B084KWNMM4) | The main controller board integrat-able with different IO devices. Features integrated BLE/WiFi
Relay Board (Already Acquired) | URL (https://digilog.pk/products/arduino-4-channel-relay-module-board) | Can be paired with ESP32-Devkit and placed inside wall-sockets to control outlets. Output Only.
Current Sensors (Zmct103c) | URL (https://digilog.pk/products/zmct103c-5a-range-single-phase-ac-active-output-onboard-precision-micro-current-transformer-module-current-sensor-for-arduino-in-p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) | Used to detect the condition of Switches (On/OFF). Moreover, it can measure the amount of current a particular appliance might be using. A cost effective solution for monitoring of power switches. To be used with ESP32-Devkit
Misc. Sensors | Please include more sensors of your choice | You can include other sensors of choice to increase the detectable variables e.g DHT11, MQ135 Gas sensor, Light sensors etc

Note: Each of the item (relays/sensors) in N4 Category require 1x ESP32 Devkit

## Summary:

N1 Category is our Edge device. All the components listed are required. In N2, I have mentioned some of the Off-the-shelf solutions that are integrat-able into our system. There is no certainty but higher probability of their compatibility. They require some reversing effort to access the terminal and program the integrated MCU. These devices are shortlisted after exploring several manufacturers and products from the internet.
N3 Category Hardware lists a pre-assembled solution capable of monitoring and controlling components along with an integrated ESP32 MCU and Wireless transceiver. There is a choice between N2, N3 and N4.
I believe the quickest way for now is to purchase N4 components as I believe they are available from the local market. They can be quickly assembled on a proto board and we can start using them. Downside is that this may not be the best looking solution. N2 hardware is a better solution but it will take some time in purchase + shipping and then disassembly of hardware in an attempt to program the chip. It may take several days to figure out the programming pattern for those N2 market products. One point to be noted is that N2 category products may not be a sustainable solution for commercialization as they are already the product of another company and there are complications involved. The best approach to commercial scaling of our solution would be to take our already tested (by then) N4 setup to a custom hardware design.

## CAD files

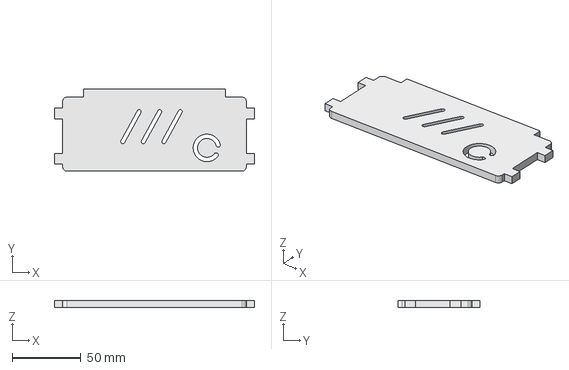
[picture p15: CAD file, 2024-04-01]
hardware/EVTY_XP1_SBcase_v1p0/CAM_Data/EVTY_bracket_custom_v1p0-Side Face.step
146.0 x 60.0 x 5.00 mm

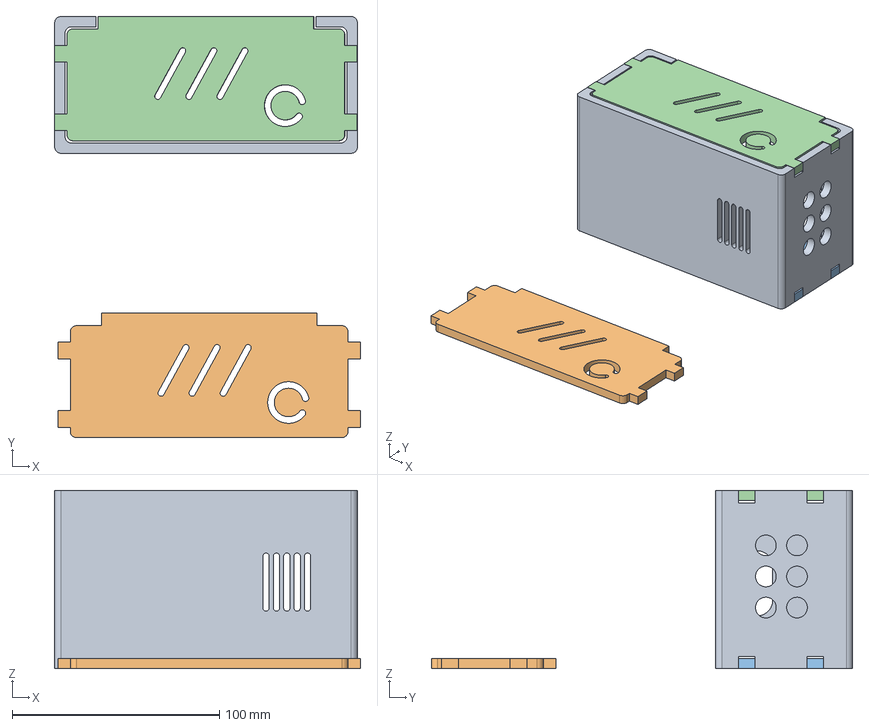
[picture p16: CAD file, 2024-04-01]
hardware/EVTY_XP1_SBcase_v1p0/src_freecad/EVTY_bracket_custom_v1p0.FCStd
147.6 x 203.2 x 86.1 mm
Prim Shell
Side Face

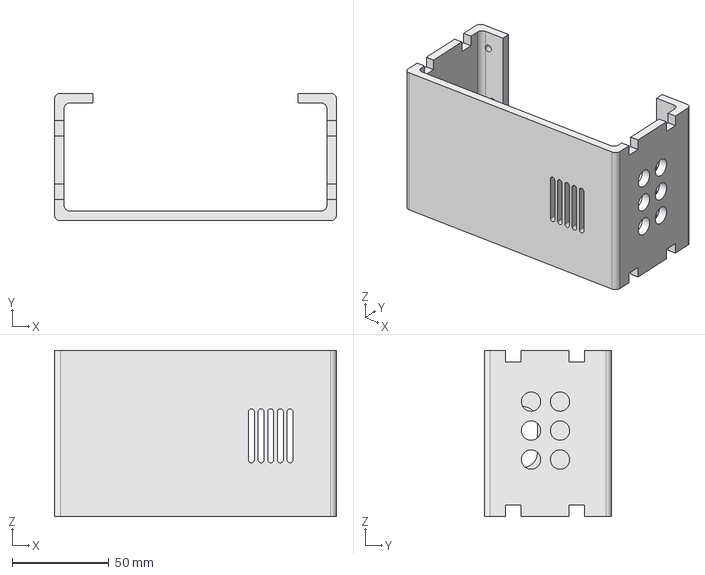
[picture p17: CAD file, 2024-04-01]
hardware/EVTY_XP1_SBcase_v1p0/CAM_Data/EVTY_bracket_custom_v1p0-Prim Shell.step
146.0 x 66.0 x 86.0 mm

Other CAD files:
hardware/EVTY_XP1_SBcase_v1p0/CAM_Data/EVTY_bracket_custom_v1p0-Prim Shell.dxf
hardware/EVTY_XP1_SBcase_v1p0/CAM_Data/EVTY_bracket_custom_v1p0-Prim Shell.stl
hardware/EVTY_XP1_SBcase_v1p0/CAM_Data/EVTY_bracket_custom_v1p0-Side Face.dxf
hardware/EVTY_XP1_SBcase_v1p0/CAM_Data/EVTY_bracket_custom_v1p0-Side Face.stl

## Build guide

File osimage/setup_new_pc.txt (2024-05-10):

===== Setting up MQTT Broker and relevant services on Linux PC/Raspberry pi replacement =====

# Install MQTT and MQTT client
sudo apt install -y mosquitto mosquitto-clients
# Install MQTT transmitter library
sudo pip3 install paho-mqtt

# To resolve Python Venv issue
sudo rm -rf /usr/lib/python3.11/EXTERNALLY-MANAGED
sudo pip3 install paho-mqtt

sudo nano /etc/mosquitto/mosquitto.conf
2) Move to the end of the file using the arrow keys and paste the following two lines:

listener 1883
allow_anonymous true

# Configure Network
nmcli dev
sudo nmcli device wifi hotspot ssid secureLAN password secureLAN ifname <replace with your WLAN interface name>

# Connect Wifi USB adapter to home network for internet
 nmcli device wifi connect LIAMAVENTA password 78900789 ifname wlx502b73c4193b

#Enable MQTT Broker
sudo systemctl enable mosquitto.service

###========================
Do each time

# Configure network if not in bashrc, else skip
Run MQTT host service

cd ~/Desktop/electrivity-main/linux_app
sudo python3 mqttapp.py

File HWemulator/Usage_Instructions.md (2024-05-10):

# Electrivity Hardware Emulator: Usage Guide

1- Connect target PC to secureLAN hotspot generated by RPI/host PC
2- Run `sudo python3 responder_hwemul.py`
3- Run `sudo txer_.sh` 
4- Enjoy :-)

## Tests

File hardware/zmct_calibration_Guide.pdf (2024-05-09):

## Tachyon Techs

Created by: M Aitesam

# Calibrate ZMCT103C

4

## th September 20XX

## OVERVIEW

Please follow the procedure below to calibrate ZMCT103C Sensors for Electrivity Project.

## PINOUT

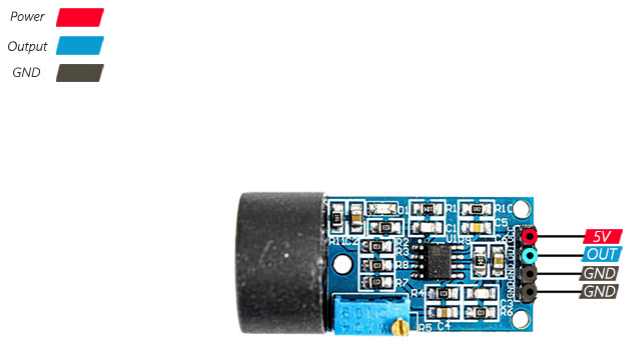
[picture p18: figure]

## Annotation

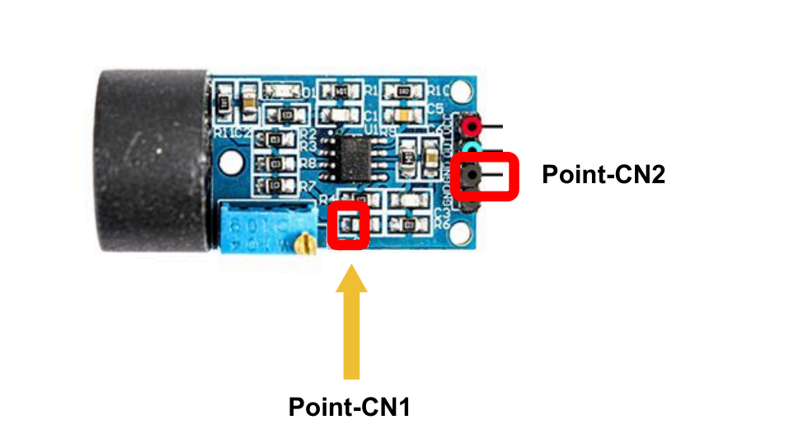
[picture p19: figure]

1. Place Multimeter probes on point-CN1 and CN2
2. Set Multimeter to Ohm measurement (>80k range)
3. Tune the Potentiometer until resistance is 20k Ohms
4. Connect to the device and check for any fluctuations in results.
5. If fluctuations are found, reset the potentiometer to max and then back to 20k.
6. Still found, try to remove any high voltage components from the surroundings of the sensor.

Please note:
Carefully wrap the GND wire around 5V and ADC wire to ensure maximum immunity to stray voltages. (see example in electrivity board #sensors 1 & 2)

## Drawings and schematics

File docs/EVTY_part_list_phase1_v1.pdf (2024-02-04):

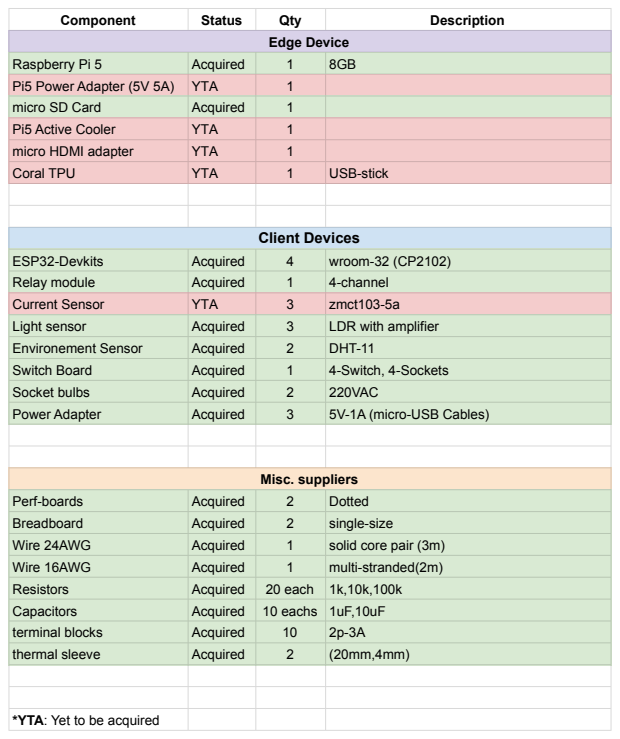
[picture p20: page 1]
Component; Status; Qty; Description; Edge Device; Raspberry Pi 5; Acquired; Pi5 Power Adapter (5V 5A); YTA; micro SD Card; Pi5 Active Cooler; micro HDMI adapter; Coral TPU; USB-stick; Client Devices; ESP32-Devkits; wroom-32 (CP2102); Relay module; 4-channel; Current Sensor; zmct103-5a; Light sensor; LDR with amplifier; Environement Sensor; DHT-11; Switch Board; 4-Switch, 4-Sockets; Socket bulbs; 220VAC; Power Adapter; 5V-1A (micro-USB Cables); Misc. suppliers; Perf-boards; Dotted; Breadboard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

*YTA: Yet to be acquired

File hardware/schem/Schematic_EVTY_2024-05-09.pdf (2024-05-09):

220VAC to 5V (1A<Imax<2A) | ESP32-Devkit-V1 | TTP223-Touch Sensor

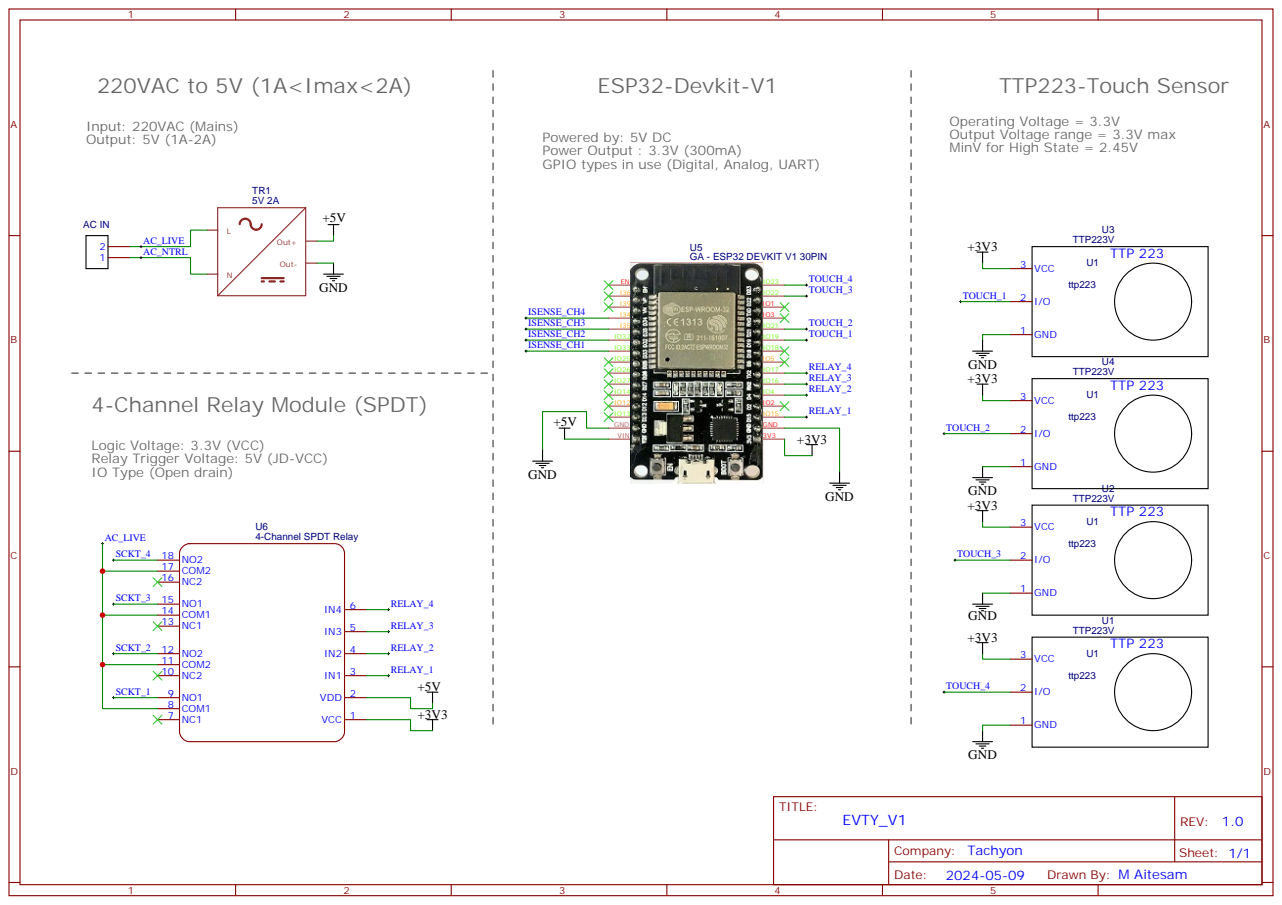
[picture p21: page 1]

Operating Voltage = 3.3V
Output Voltage range = 3.3V max
MinV for High State = 2.45V

Powered by: 5V DC
Power Output : 3.3V (300mA)
GPIO types in use (Digital, Analog, UART)

4-Channel Relay Module (SPDT)

Logic Voltage: 3.3V (VCC)
Relay Trigger Voltage: 5V (JD-VCC)
IO Type (Open drain)

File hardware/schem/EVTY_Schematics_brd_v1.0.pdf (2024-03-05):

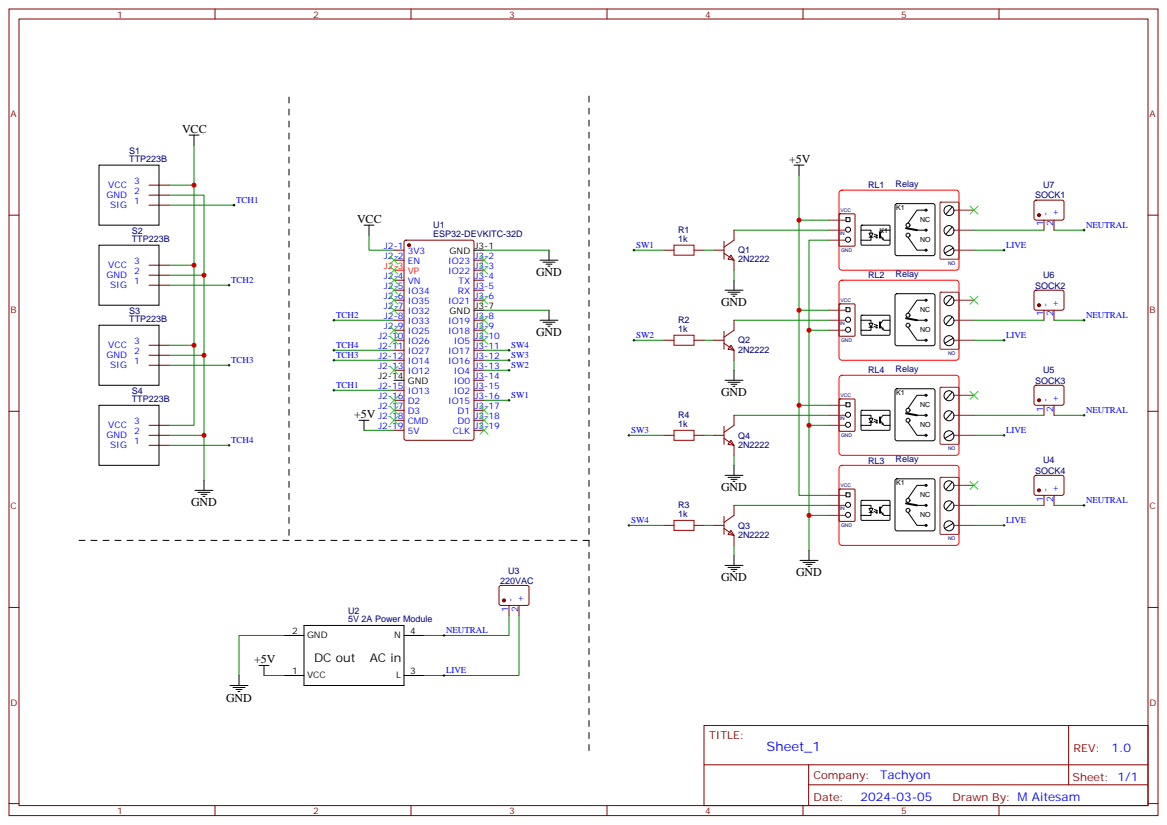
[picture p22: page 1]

GND 2
DC out AC in
VCC 1

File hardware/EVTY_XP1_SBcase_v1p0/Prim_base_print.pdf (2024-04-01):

Document Name: EVTY_bracket_custom_v1p0

Page / Page_projection
Page001 / Page_top
Page002 / Page_side
Page003 / Page_LR
Page004 / Page_bottom

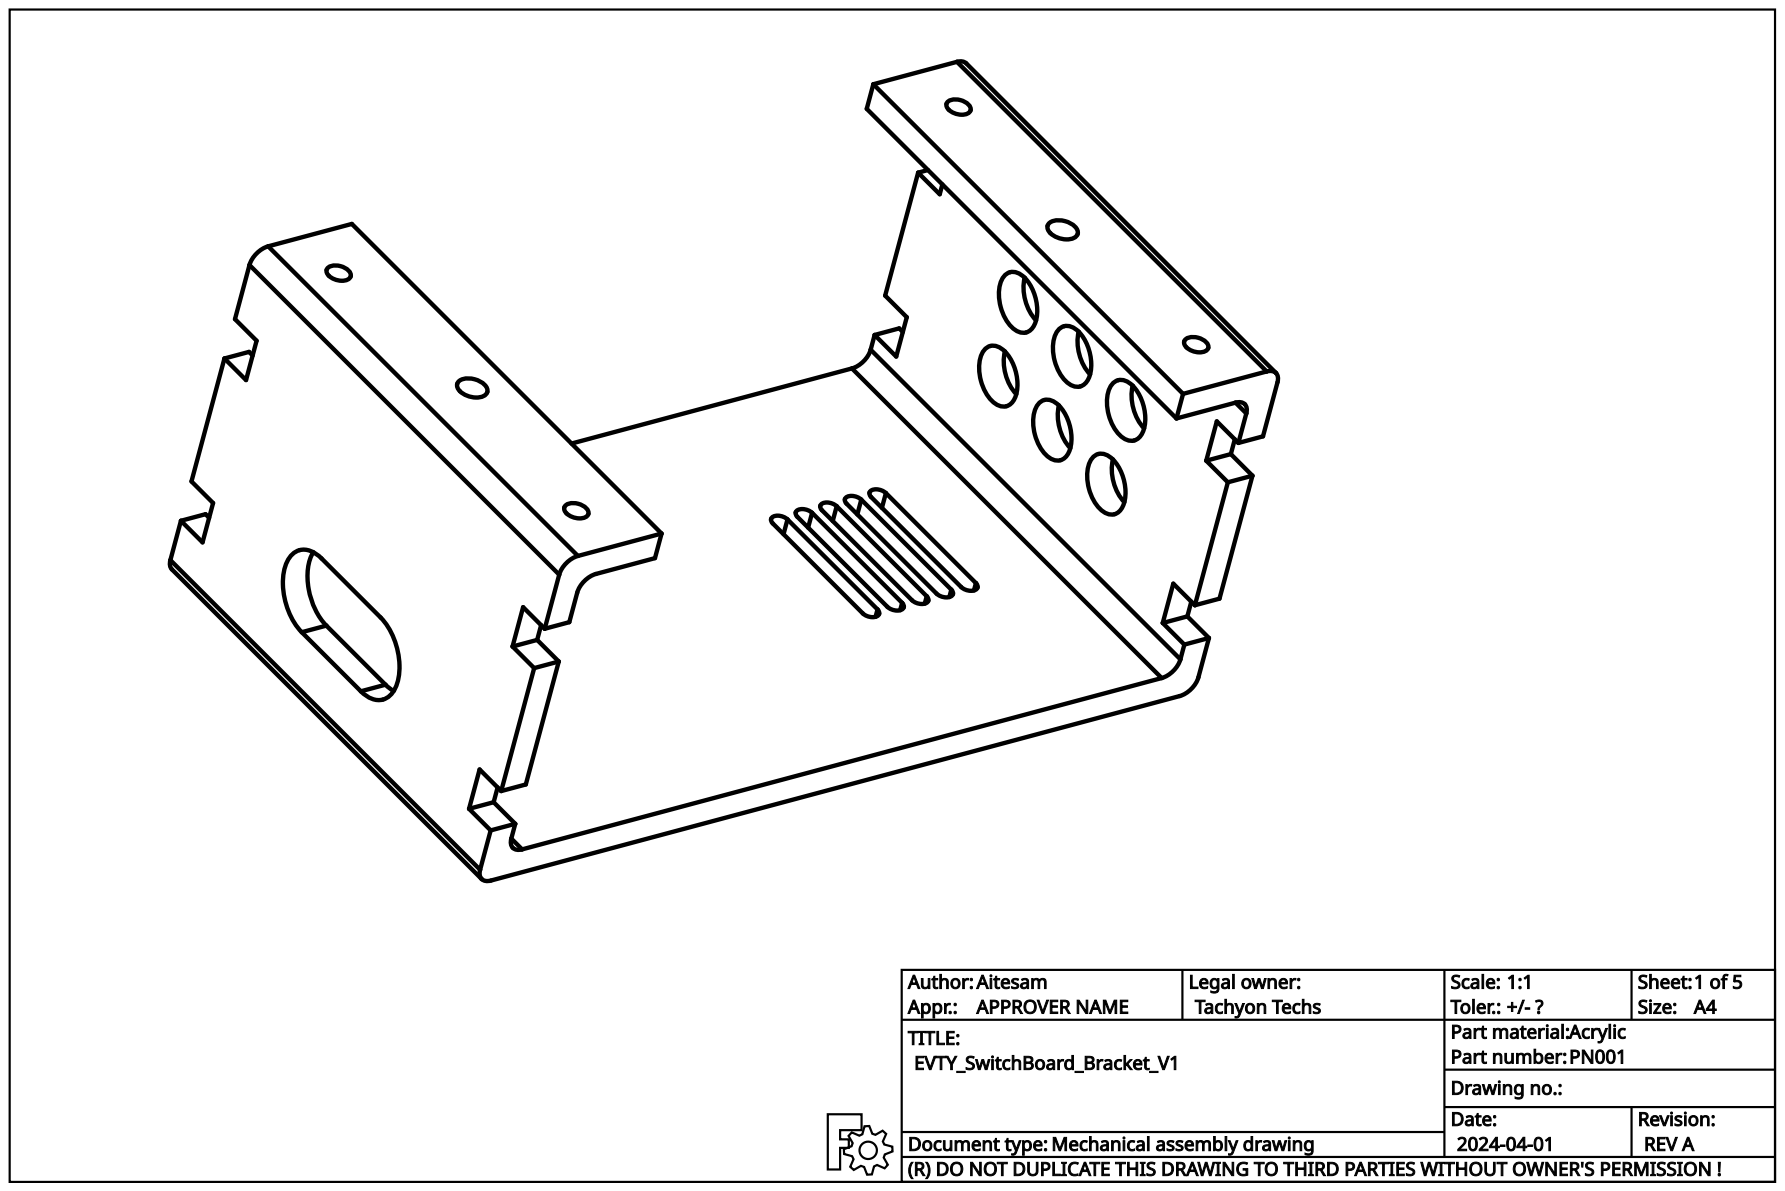
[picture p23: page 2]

3 12
2

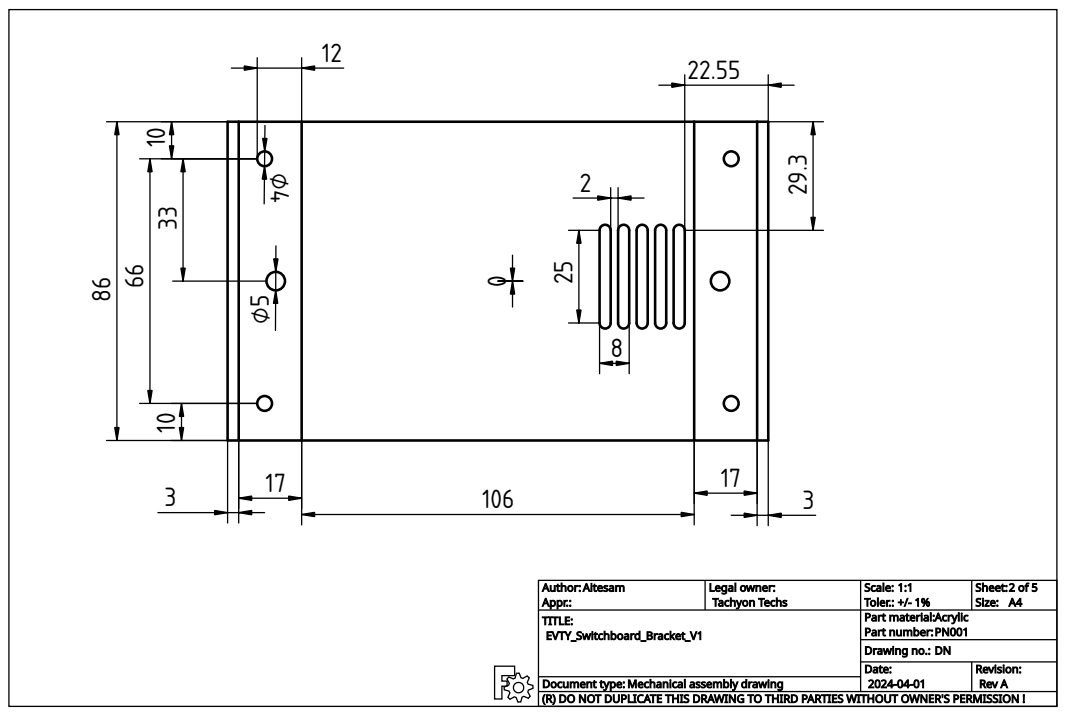
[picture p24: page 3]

2

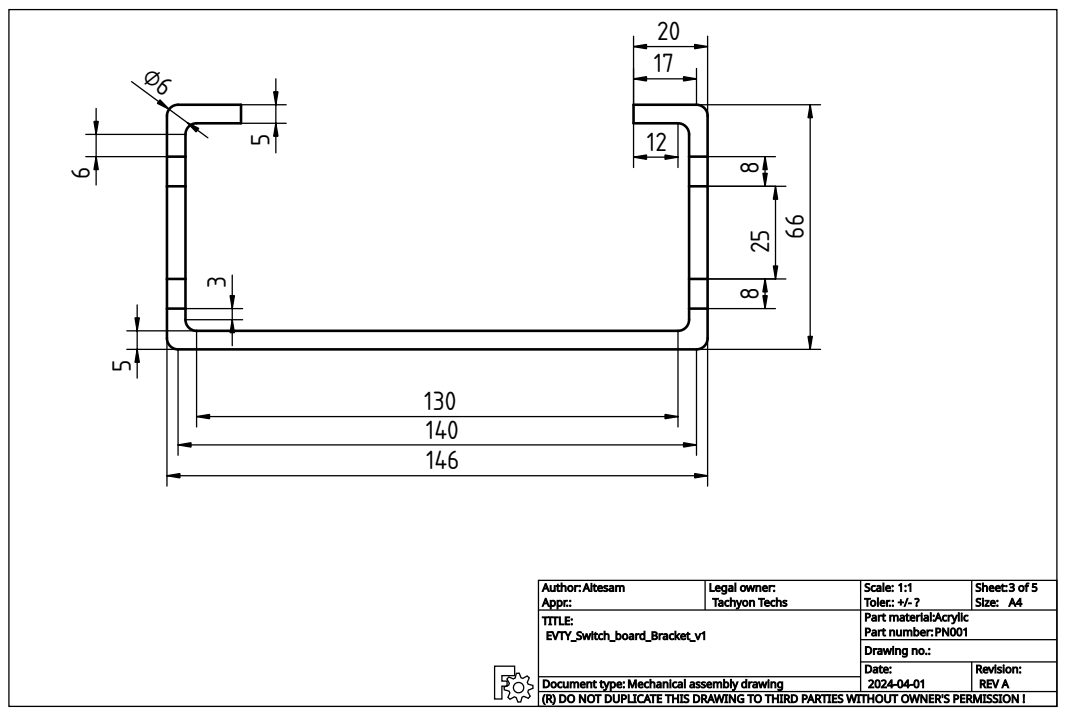
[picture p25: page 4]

8

6

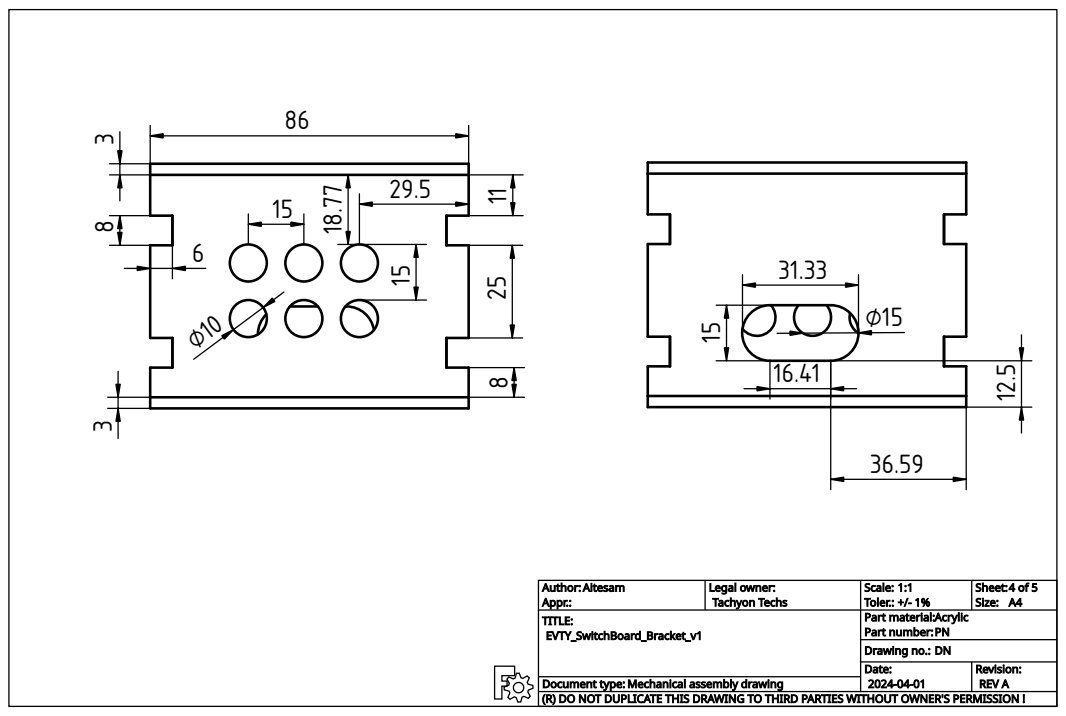
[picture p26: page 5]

3

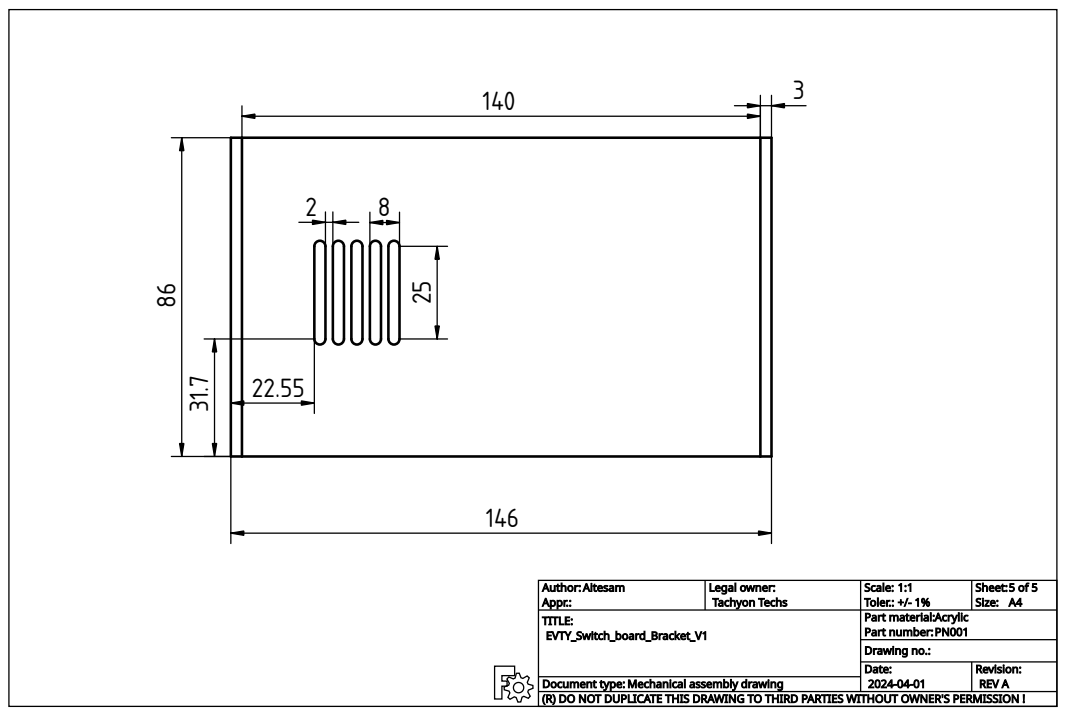
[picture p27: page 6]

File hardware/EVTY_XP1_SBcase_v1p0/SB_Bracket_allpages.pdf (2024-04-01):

Document Name: EVTY_bracket_custom_v1p0

Page / Page_projection
Page001 / Page_top
Page002 / Page_side
Page003 / Page_LR
Page004 / Page_bottom
Page005 / Projection_Side
Page006 / Top_Dim


3 12
2


2


8

6


3


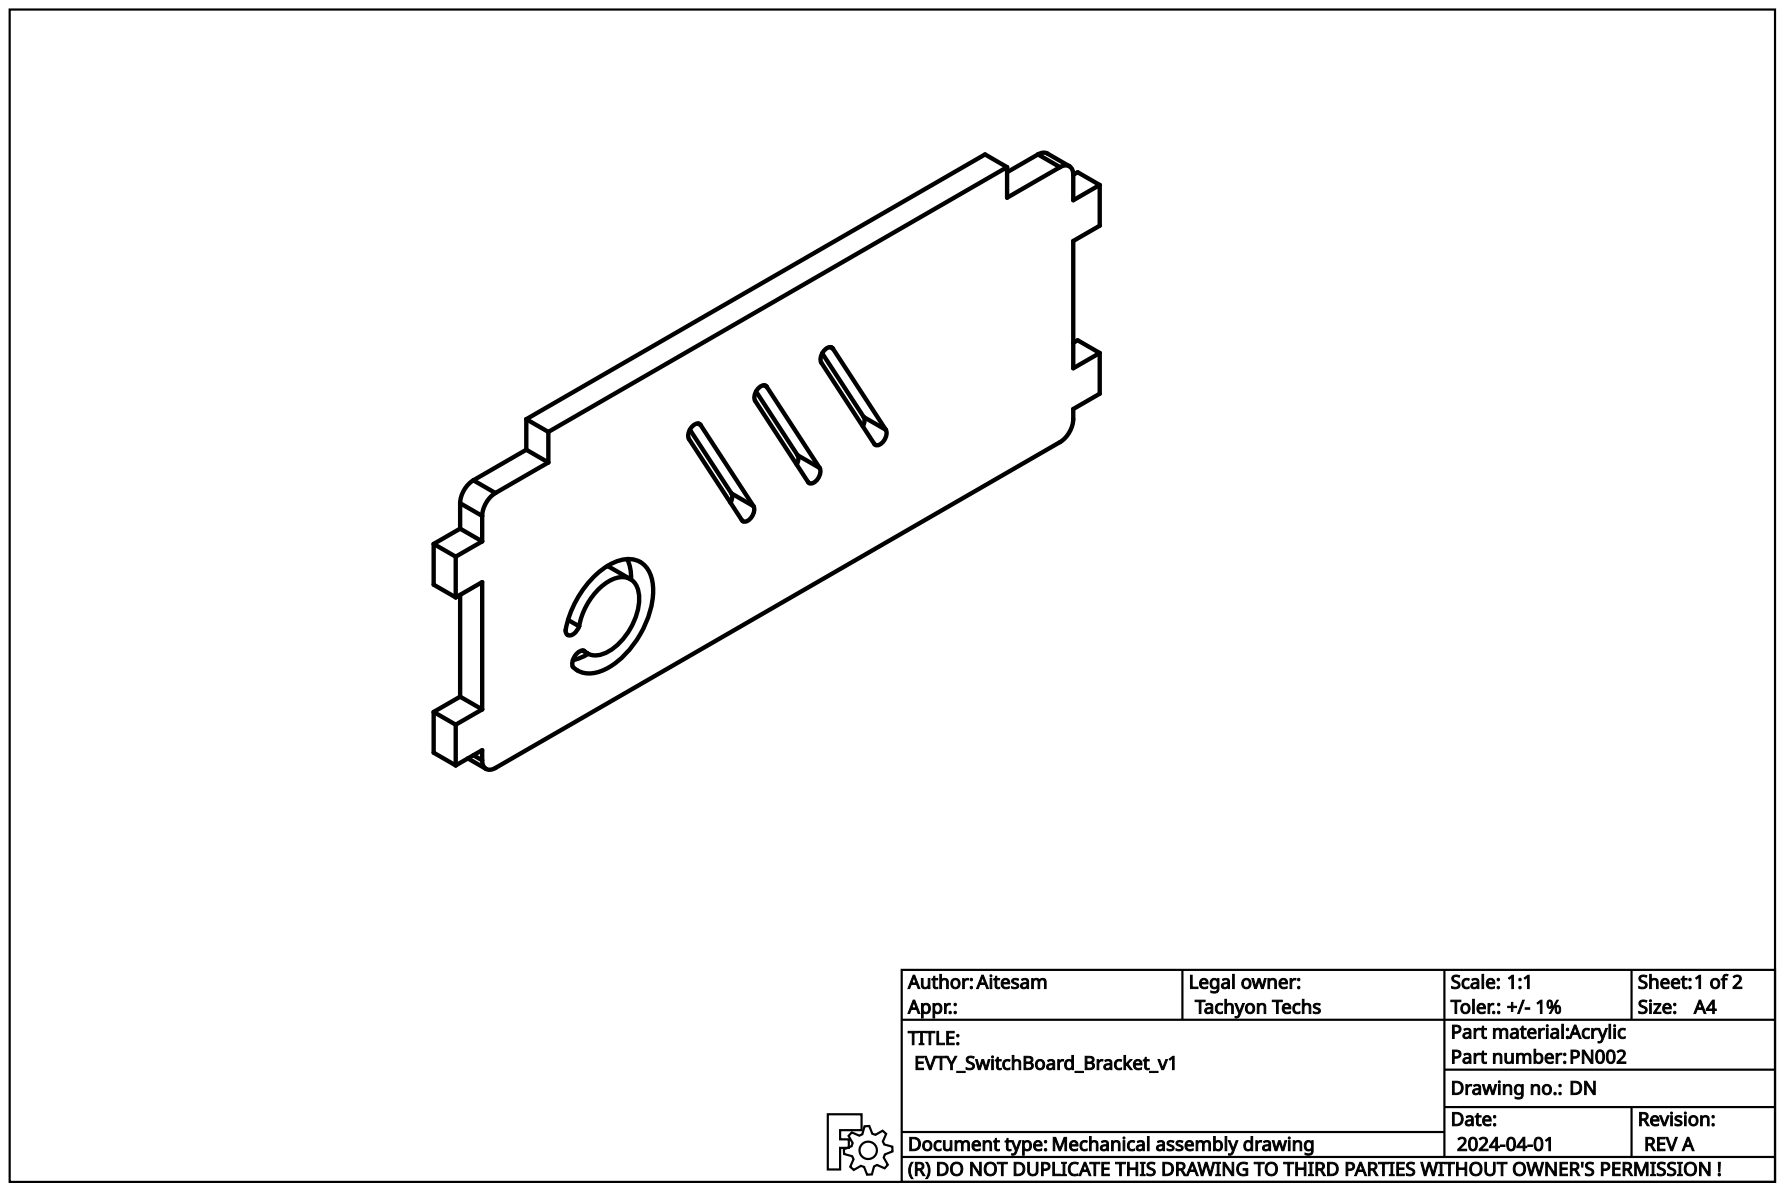
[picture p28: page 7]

10

412

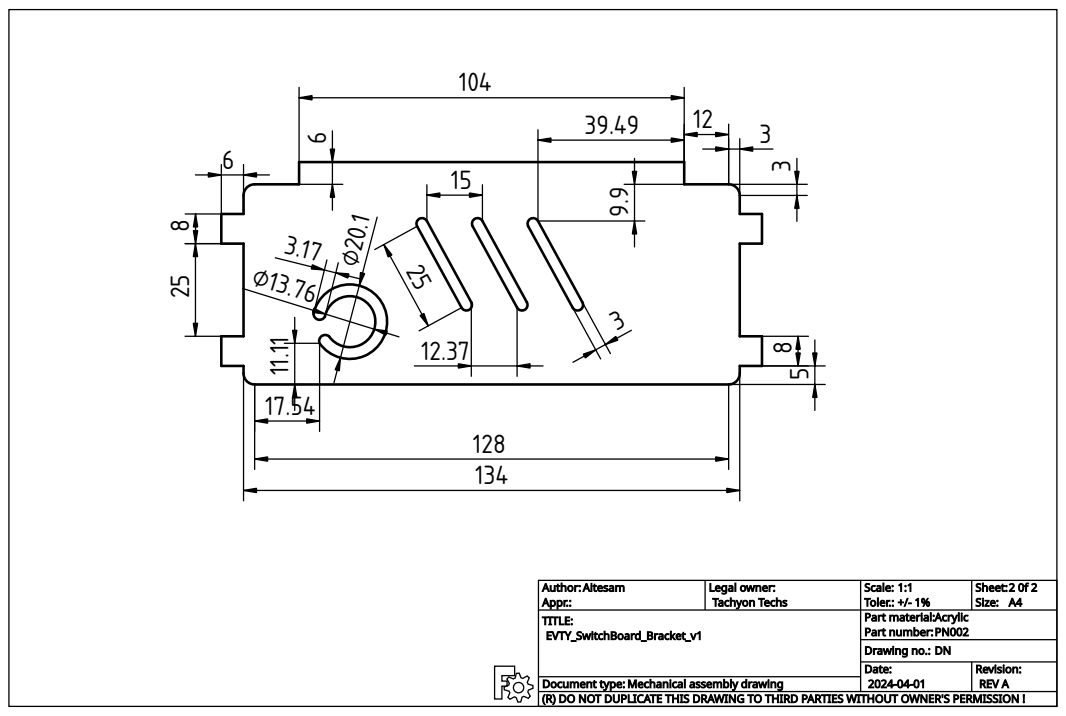
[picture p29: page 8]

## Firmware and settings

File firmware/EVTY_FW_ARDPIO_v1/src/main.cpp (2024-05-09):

/*
*
*  Project: PRISM
*  An Egde IoT System for home automation
*  
*  Author: aitesam961
*  
*  This is the main source file for ESP32 firmware written in arduino framework
*  
*
*/
#include<Arduino.h>
#include <WiFi.h>
#include "EmonLib.h"  
#include <PubSubClient.h>

#define  mains_voltage 220;

const char* ssid            = "secureLAN";
const char* password        = "secureLAN";
const char* mqttServer      = "10.42.0.1";
const int mqttPort          = 1883;
const char* mqttClientID    = "ESP32_ROOM_4";

const char* top_swh_1 = "prism/board4/switch1";
const char* top_swh_2 = "prism/board4/switch2";
const char* top_swh_3 = "prism/board4/switch3";
const char* top_swh_4 = "prism/board4/switch4";

const char* top_tch_1 = "prism/board4/touch1";
const char* top_tch_2 = "prism/board4/touch2";
const char* top_tch_3 = "prism/board4/touch3";
const char* top_tch_4 = "prism/board4/touch4";

const char* top_pch_1 = "prism/board4/pwrch1";
const char* top_pch_2 = "prism/board4/pwrch2";
const char* top_pch_3 = "prism/board4/pwrch3";
const char* top_pch_4 = "prism/board4/pwrch4";


const int switch1_pin     = 15;
const int switch2_pin     = 4;
const int switch3_pin     = 16;
const int switch4_pin     = 17;
 
const int touch1_pin      = 19;
const int touch2_pin      = 21;
const int touch3_pin      = 22;
const int touch4_pin      = 23;
 
const int led_pin         = 2 ;  

const int cts1_pin        = 33;
const int cts2_pin        = 32;
const int cts3_pin        = 35;
const int cts4_pin        = 34;

const int num_i_read      = 4;

uint8_t ttemp1 = 0;
uint8_t ttemp2 = 0;
uint8_t ttemp3 = 0;
uint8_t ttemp4 = 0;

double    Irms1 = 0;
double    Irms2 = 0;
double    Irms3 = 0;
double    Irms4 = 0;

u_int16_t powerch1, powerinitch1 = 0;
u_int16_t powerch2, powerinitch2 = 0;
u_int16_t powerch3, powerinitch3 = 0;
u_int16_t powerch4, powerinitch4 = 0;

char pch1[16];
char pch2[16];
char pch3[16];
char pch4[16];

uint16_t ct_iter_trace  = 0;

int avgfifo1[num_i_read] = {0};
int avgfifo2[num_i_read] = {0};
int avgfifo3[num_i_read] = {0};
int avgfifo4[num_i_read] = {0};


WiFiClient espClient;
PubSubClient client(espClient);

EnergyMonitor emon1;
EnergyMonitor emon2; 
EnergyMonitor emon3;  
EnergyMonitor emon4; 

void callback(char* topic, byte* payload, unsigned int length) {
  String message = "";
  for (int i = 0; i < length; i++) {
    message += (char)payload[i];
  }
  if (String(topic) == top_swh_1) {
    if (message == "on") {
      digitalWrite(switch1_pin, LOW);
      Serial.println("Relay-1 turned ON");
    } else if (message == "off") {
      digitalWrite(switch1_pin, HIGH);
      Serial.println("Relay-1 turned OFF");
    }
  }
  if (String(topic) == top_swh_2) {
    if (message == "on") {
      digitalWrite(switch2_pin, LOW);
      Serial.println("Relay-2 turned ON");
    } else if (message == "off") {
      digitalWrite(switch2_pin, HIGH);
      Serial.println("Relay-2 turned OFF");
    }
  }
  if (String(topic) == top_swh_3) {
    if (message == "on") {
      digitalWrite(switch3_pin, LOW);
      Serial.println("Relay-3 turned ON");
    } else if (message == "off") {
      digitalWrite(switch3_pin, HIGH);
      Serial.println("Relay-3 turned OFF");
    }
  }
  if (String(topic) == top_swh_4) {
    if (message == "on") {
      digitalWrite(switch4_pin, LOW);
      Serial.println("Relay-4 turned ON");
    } else if (message == "off") {
      digitalWrite(switch4_pin, HIGH);
      Serial.println("Relay-4 turned OFF");
    }
  }
}


void reconnect() {
  while (!client.connected()) {
    Serial.print("Connecting to MQTT Broker...");
    if (client.connect(mqttClientID)) {
        digitalWrite(led_pin, LOW);
        Serial.println("connected");
        client.subscribe(top_swh_1);
        client.subscribe(top_swh_2);
        client.subscribe(top_swh_3);
        client.subscribe(top_swh_4);
    } else {
        Serial.print("failed, rc=");
        Serial.print(client.state());
        Serial.println(" trying again in 5 seconds");
        digitalWrite(led_pin, HIGH);
        delay(2500);
        digitalWrite(led_pin, LOW);
        delay(2500);
    }
  }
}



void setup() {
  Serial.begin(115200);
  pinMode(led_pin, OUTPUT);
  digitalWrite(led_pin, HIGH);
  pinMode(touch1_pin, INPUT);
  pinMode(touch2_pin, INPUT);
  pinMode(touch3_pin, INPUT);
  pinMode(touch4_pin, INPUT);

  pinMode(switch1_pin, OUTPUT);
  pinMode(switch2_pin, OUTPUT);
  pinMode(switch3_pin, OUTPUT);
  pinMode(switch4_pin, OUTPUT);

  emon1.current(cts1_pin, 32.59);  
  emon2.current(cts2_pin, 32.59); 
  emon3.current(cts3_pin, 32.59); 
  emon4.current(cts4_pin, 32.59); 

  digitalWrite(switch1_pin, HIGH);
  digitalWrite(switch2_pin, HIGH);
  digitalWrite(switch3_pin, HIGH);
  digitalWrite(switch4_pin, HIGH);
  WiFi.begin(ssid, password);
  while (WiFi.status() != WL_CONNECTED) {
    delay(500);
    Serial.print(".");
  }
  Serial.println("");
  Serial.println("WiFi connected");
  client.setServer(mqttServer, mqttPort);
  client.setCallback(callback);
}



void loop() {
  if (!client.connected()) {
    digitalWrite(led_pin, HIGH);
    digitalWrite(switch1_pin, HIGH);
    digitalWrite(switch2_pin, HIGH);
    digitalWrite(switch3_pin, HIGH);
    digitalWrite(switch4_pin, HIGH);
    reconnect();
  }
  client.loop();
  
  uint8_t switchState1 = digitalRead(touch1_pin);
  if (switchState1 == 1) {
    if(ttemp1 == 0){
      client.publish(top_tch_1, "high");
      Serial.println("Touch-1 HIGH");
      ttemp1 = 1;
    }
  }
  else{
    ttemp1 = 0;
    Serial.println("Resetting_TTEMP");
  }

  uint8_t switchState2 = digitalRead(touch2_pin);
  if (switchState2 == 1) {
    if(ttemp2 == 0){
      client.publish(top_tch_2, "high");
      Serial.println("Touch-2 HIGH");
      ttemp2 = 1;
    }
  }
  else{
    ttemp2 = 0;
    Serial.println("Resetting_TTEMP");
  }

  uint8_t switchState3 = digitalRead(touch3_pin);
  if (switchState3 == 1) {
    if(ttemp3 == 0){
      client.publish(top_tch_3, "high");
      Serial.println("Touch-3 HIGH");
      ttemp3 = 1;
    }
  }
  else{
    ttemp3 = 0;
    Serial.println("Resetting_TTEMP");
  }

  uint8_t switchState4 = digitalRead(touch4_pin);
  if (switchState4 == 1) {
    if(ttemp4 == 0){
      client.publish(top_tch_4, "high");
      Serial.println("Touch-4 HIGH");
      ttemp4 = 1;
    }
  }
  else{
    ttemp4 = 0;
    Serial.println("Resetting_TTEMP");
  }

  Irms1 = emon1.calcIrms(1480);
  Irms2 = emon2.calcIrms(1480);
  Irms3 = emon3.calcIrms(1480);
  Irms4 = emon4.calcIrms(1480);

  powerch1  = (Irms1/100)*mains_voltage;
  powerch2  = (Irms2/100)*mains_voltage;
  powerch3  = (Irms3/100)*mains_voltage;
  powerch4  = (Irms4/100)*mains_voltage;

if(ct_iter_trace < num_i_read){
  avgfifo1[ct_iter_trace] = powerch1;
  avgfifo2[ct_iter_trace] = powerch2;
  avgfifo3[ct_iter_trace] = powerch3;
  avgfifo4[ct_iter_trace] = powerch4;

  ct_iter_trace +=  1;
}
else{
  ct_iter_trace = 0;

  powerinitch1  = ((avgfifo1[0]+avgfifo1[1]+avgfifo1[2]+avgfifo1[3])/4);
  powerinitch2  = ((avgfifo2[0]+avgfifo2[1]+avgfifo2[2]+avgfifo2[3])/4);
  powerinitch3  = ((avgfifo3[0]+avgfifo3[1]+avgfifo3[2]+avgfifo3[3])/4);
  powerinitch4  = ((avgfifo4[0]+avgfifo4[1]+avgfifo4[2]+avgfifo4[3])/4);

  powerinitch1  = powerinitch1 < 5 ? 0 : powerinitch1;
  powerinitch2  = powerinitch2 < 5 ? 0 : powerinitch2;
  powerinitch3  = powerinitch3 < 5 ? 0 : powerinitch3;
  powerinitch4  = powerinitch4 < 5 ? 0 : powerinitch4;

  // data type conversion for transfer
  snprintf(pch1, sizeof(pch1), "%u", powerinitch1);
  snprintf(pch2, sizeof(pch2), "%u", powerinitch2);
  snprintf(pch3, sizeof(pch3), "%u", powerinitch3);
  snprintf(pch4, sizeof(pch4), "%u", powerinitch4);

  Serial.print("Power Consumption, Channel 1  : "); Serial.println(pch1);
  Serial.print("Power Consumption, Channel 2  : "); Serial.println(pch2);
  Serial.print("Power Consumption, Channel 3  : "); Serial.println(pch3);
  Serial.print("Power Consumption, Channel 4  : "); Serial.println(pch4);

  client.publish(top_pch_1, pch1);
  client.publish(top_pch_2, pch2);
  client.publish(top_pch_3, pch3);
  client.publish(top_pch_4, pch4);
}

  delay(100);
  Serial.println("Tick..........!");
}

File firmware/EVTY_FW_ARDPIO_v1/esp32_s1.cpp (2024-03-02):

/*
*
*  Project: PRISM
*  An Egde IoT System for home automation
*  
*  Author: aitesam961
*  
*  This is the main source file for ESP32 firmware written in arduino framework
*  
*
*/
#include <WiFi.h>
#include <PubSubClient.h>
#include <Adafruit_Sensor.h>
#include <DHT.h>


const char* ssid            = "LIAMAVENTA";
const char* password        = "78900789";
const char* mqttServer      = "192.168.1.94";
const int mqttPort          = 1883;
const char* mqttClientID    = "ESP32_SENSOR_ ROOM_1";

const char* top_dht_temp    = "prism/sboard1/sensor1";
const char* top_dht_humi    = "prism/sboard1/sensor2";
const char* top_ldr_status  = "prism/sboard1/sensor3";

const int DHTPIN            = 15;
const int ldr_pin           = 4;

const int led_pin         = 2 ;  

#define DHTTYPE DHT11

WiFiClient espClient;
PubSubClient client(espClient);

DHT dht(DHTPIN, DHTTYPE);

void callback(char* topic, byte* payload, unsigned int length) {
    String message = "";
    for (int i = 0; i < length; i++) {
        message += (char)payload[i];
    }
}


void reconnect() {
  while (!client.connected()) {
    Serial.print("Connecting to MQTT Broker...");
    if (client.connect(mqttClientID)) {
        digitalWrite(led_pin, LOW);
        Serial.println("connected");
    } else {
        Serial.print("failed, rc=");
        Serial.print(client.state());
        Serial.println(" trying again in 5 seconds");
        digitalWrite(led_pin, HIGH);
        delay(2500);
        digitalWrite(led_pin, LOW);
        delay(2500);
    }
  }
}



void setup() {
  Serial.begin(115200);
  pinMode(led_pin, OUTPUT);
  digitalWrite(led_pin, HIGH);
  pinMode(ldr_pin, INPUT);

  
  WiFi.begin(ssid, password);
  while (WiFi.status() != WL_CONNECTED) {
    delay(500);
    Serial.print(".");
  }
  Serial.println("");
  Serial.println("WiFi connected");
  client.setServer(mqttServer, mqttPort);
  client.setCallback(callback);
}



void loop() {
  if (!client.connected()) {
    digitalWrite(led_pin, HIGH);
    reconnect();
  }
  client.loop();

  int ldrState = digitalRead(ldr_pin);
  if (ldrState == HIGH) {
    client.publish(top_ldr_status, "high");
    Serial.println("LDR HIGH");
  }
  else{
    client.publish(top_ldr_status, "low");
    Serial.println("LDR LOW");
  }

  u_int8_t dht_temp = dht.readTemperature();
  u_int8_t dht_humi = dht.readHumidity();

  client.publish(top_dht_temp, String(dht_temp).c_str());
  Serial.println("TEMP");
  Serial.print(String(dht_temp).c_str());
  client.publish(top_dht_humi, String(dht_humi).c_str());
  Serial.println("HUMI");
  Serial.print(String(dht_humi).c_str());

  int ldr_state = digitalRead(ldr_pin);
  if (ldr_state == HIGH) {
    client.publish(top_ldr_status, "high");
    Serial.println("Light HIGH");
  }
  else{
    client.publish(top_ldr_status, "low");
    Serial.println("Light LOW");
  }
  delay(100);
}

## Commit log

2024-02-06 Add BT_addr_scan example and BT_ADDR for ESP32-A1
2024-02-23 [FIX] LED status blink sequence
2024-02-25 ADD: Print date and Time with messgaes
2024-02-28 IMPROVEMENT: Robust power off sequence for disconnect
2024-03-11 [FW] Pinout and noise adjustment
    [main.cpp]
2024-03-21 ADD more verbose prints
2024-04-01 [HW] Create freecad src for bracker
    [EVTY_bracket_custom_v1p0.FCStd]
2024-04-01 [HW] Create CAM data
    [EVTY_bracket_custom_v1p0-Prim Shell.step, EVTY_bracket_custom_v1p0-Prim Shell.stl, EVTY_bracket_custom_v1p0-Side Face.step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]
2024-04-01 [HW] Create dimension Docs for Bracket
2024-05-09 [FW] Complete support for ZMCT103c & power measurement
2024-05-09 [HW] Add ZMCT Calibration Guide
